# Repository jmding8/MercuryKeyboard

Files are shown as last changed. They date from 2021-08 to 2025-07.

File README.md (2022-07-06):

# Mercury

Mercury is a row staggered keyboard with 42 keys that kind of looks like a pair of wings. It is primarily designed as a split, wireless, low-profile keyboard. Other build configurations are also possible, but full feature parity is not guaranteed. If you are looking for a 40% keyboard with thumb keys and a conventional row staggered layout, then Mercury might be for you.

With MBK keycaps, Mercury is 19mm thick from table to typing-surface. Its batteries are fully enclosed and protected inside the case of the keyboard. Default firmware is pre-compiled with a keymap that I personally use exclusively and on a daily basis.

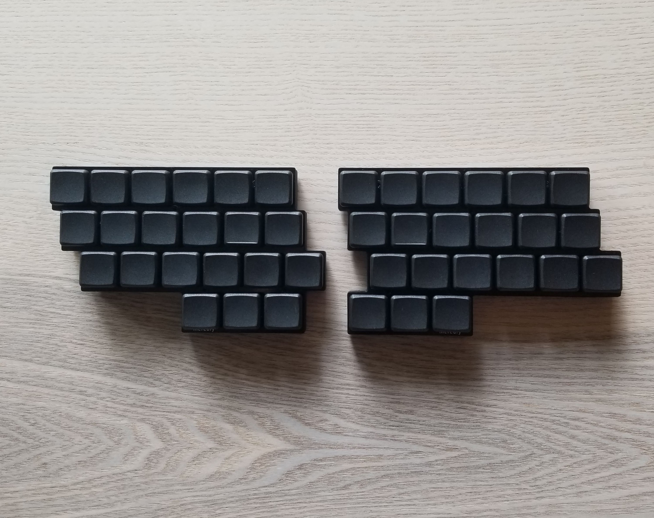
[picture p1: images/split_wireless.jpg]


## Resources
1. [Bill of materials](/text/bill_of_materials.md)
1. [Build guide](/text/build_guide.md)
1. [Manufacturing notes](/text/manufacturing_notes.md)
1. [Firmware and keymap notes](/text/firmware_notes.md)

## Alternative Configurations

* MX-style, full-height switches
* USB wired
* Monoblock, aka non-split

1. Split, wired, full-height
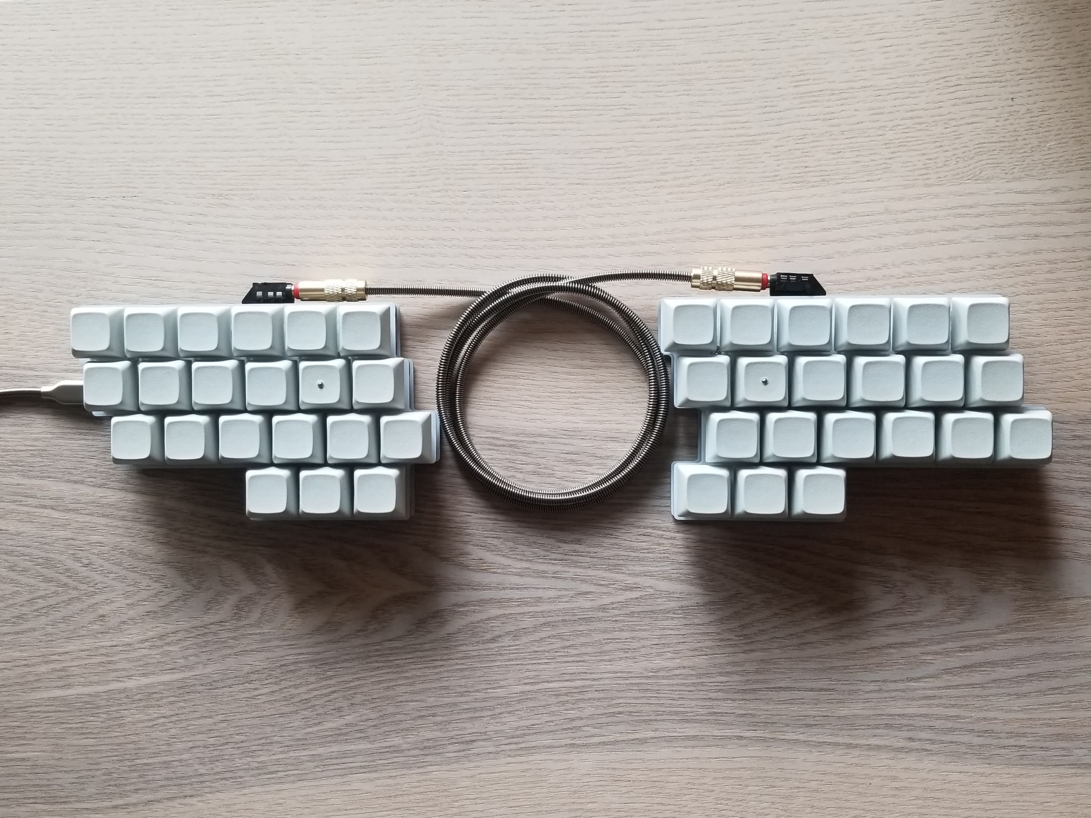
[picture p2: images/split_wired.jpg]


1. Monoblock, wireless, low-profile
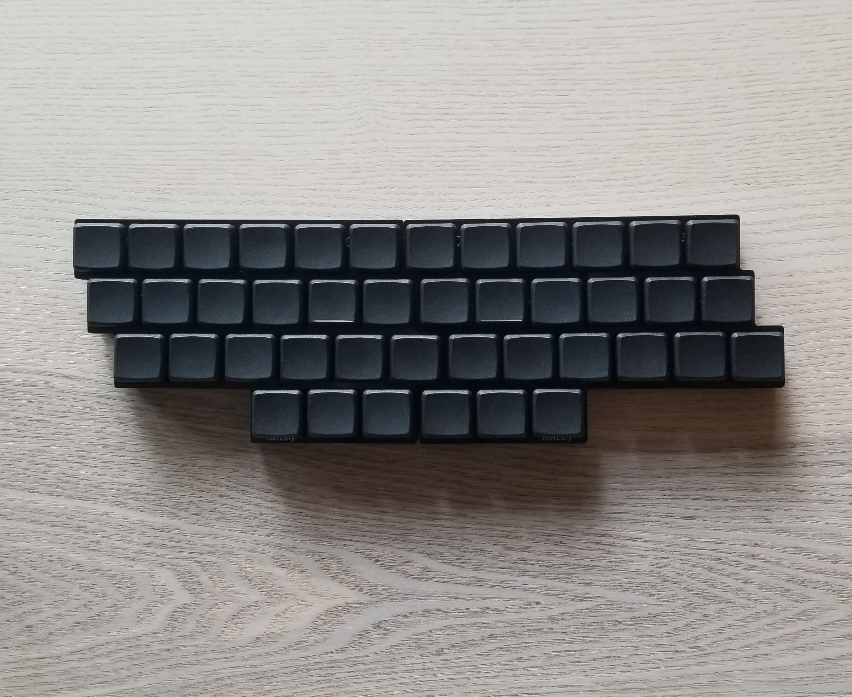
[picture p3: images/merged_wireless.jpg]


1. Monoblock, wired, low-profile
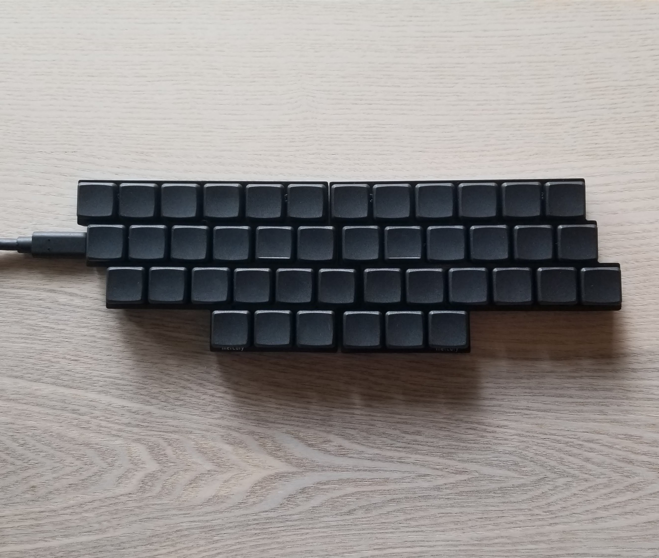
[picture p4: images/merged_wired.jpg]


## To-Do

1. Upload ZMK source.
2. Merge shield into ZMK main.

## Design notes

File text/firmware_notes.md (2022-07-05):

# Firmware and Keymap Notes

## Flashing Firmware For Wireless Builds
- See [the ZMK documentation on how to flash](https://zmk.dev/docs/user-setup#flashing-uf2-files) the firmware binaries to your keyboard.
- The default firmware binary files [are located here](/Firmware/), and are named **zmk_left.uf2** and **zmk_right.uf2**.

## Default Keymap
Mercury's default keymap seeks to achieve the following goals:
* All keyboard shortcuts should be accessible
* Reduce the use of the outer pinky columns
* Minimize the learning curve, especially:
  * Minimize the need for user-tuning of timing parameters (`tapping-term`)
  * Minimize the requirement for strict key-up order

To achieve these goals, we use several combos

### Modifier combos
1. `K` + `L` -> `Right Shift`
1. `S` + `D` -> `Left Shift`
1. `D` + `F` -> `Number Layer`
1. `S` + `D` + `F` -> `Shifted Number Layer`
1. `A` + `Function Layer` -> `Shifted Function Layer`

### Other combos
1. `X` + `C` -> `Tab`
1. `C` + `V` -> `Esc`
1. `M` + `Comma` -> `Caps Lock`
1. `H` + `J` -> `Menu Key` (opens the context menu, similar to `Right Click` in Windows)
1. `Q` + `W` + `E` -> activate `System Layer` for the next keypress

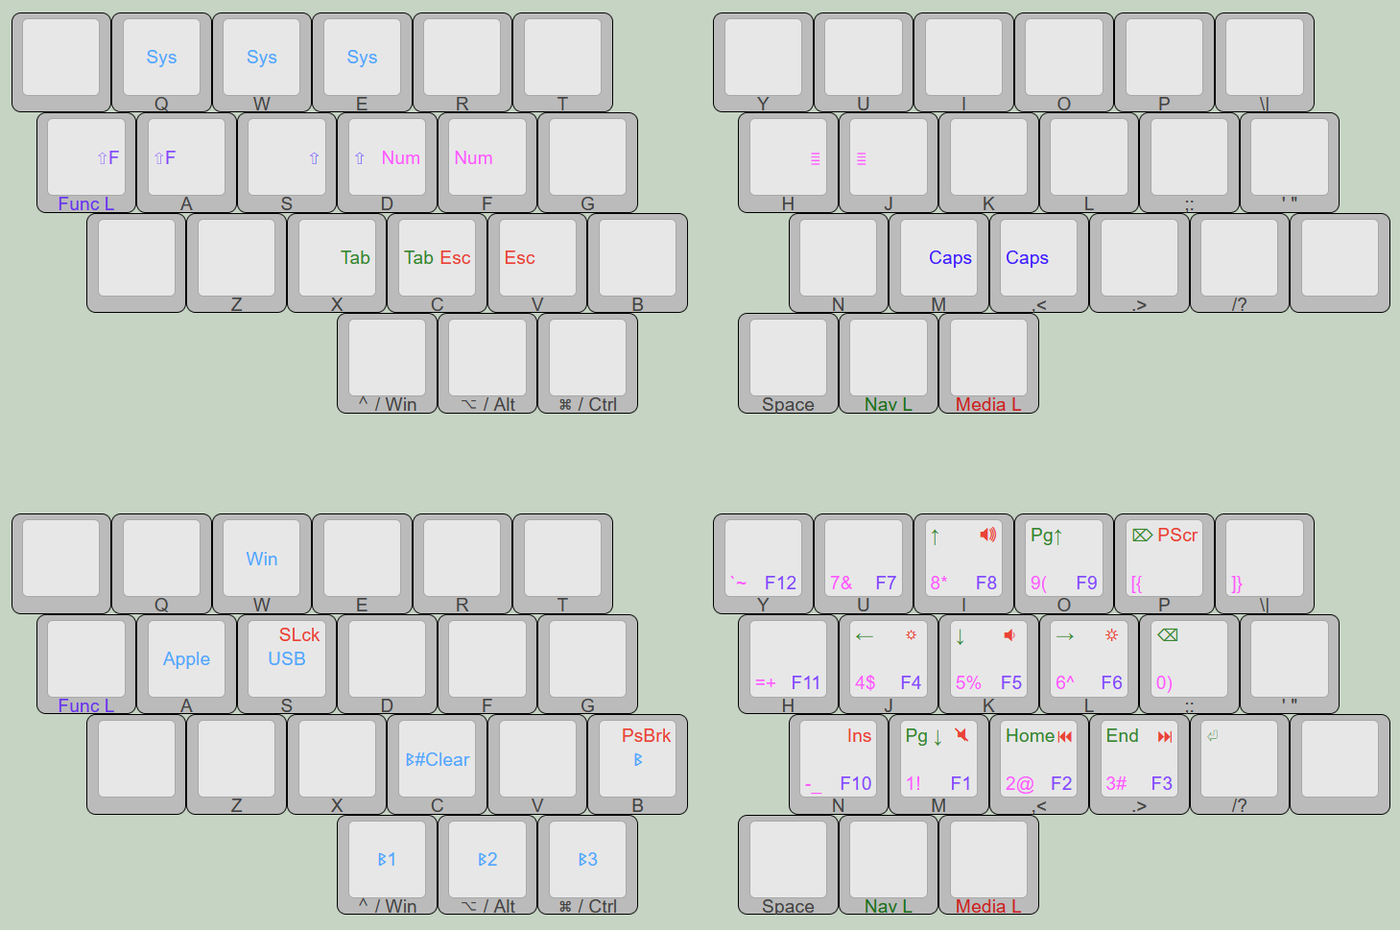
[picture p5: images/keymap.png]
keymap


## Bluetooth 
- After flashing the firmware, you will likely need to follow [the settings reset procedure described here](https://zmk.dev/docs/troubleshooting#split-keyboard-halves-unable-to-pair) to get the two keyboard halves to bond to each other, and to get the keyboard to pair with your computer.
- There are three Bluetooth profiles that can be used to pair with three computers. To select a specific profile, activate the `System Layer`, then press `Bt1` / `Bt2` / `Bt3` (left thumb cluster).
- To clear a Bluetooth profile so that it can pair with a different host, activate the profile you wish to clear. Then activate `System Layer`, and press  `BtClear` (`C` key).
- By default, the keyboard will always prefer to send output to USB when a USB cable is connected. If you want to send output over Bluetooth while chargin your keyboard over USB, you will need to enable Bluetooth-preferred output. To do this, activate `System Layer`, then press `Bluetooth` (`B` key). To enable USB-preferred output isntead, activate `System Layer`, then press `USB` (`S` key).

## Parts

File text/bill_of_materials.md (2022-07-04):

# Bill of Materials

## PCBs
- [ ] 1x left hand plate
- [ ] 1x left hand base
- [ ] 1x right-hand plate
- [ ] 1x right-hand base
- [ ] 1x logic PCB

## Additional Parts
- [ ] 42x switches, standard MX or Kailh PG1350 Chocolate
- [ ] 42x 1u keycaps
- [ ] Controller boards
  - Split + wireless: 2x Nice!Nano
  - Monoblock + wireless: 1x Nice!Nano
  - Split + wired: 2x ProMicro (Elite-C and Proton-C not verified to work)
  - Monoblock + wired: 1x ProMicro (Elite-C and Proton-C not verified to work)
- [ ] 2x reset switches, YD-3414, [available on AliExpress](https://www.aliexpress.com/item/33032223116.html)
- [ ] 24x M2 screws. 4mm long, wafer head <0.5mm thick, [available on AliExpress](https://www.aliexpress.com/item/4001149177246.html).
- [ ] 12x M2 cylindrical standoffs, <3.5mm diameter, [available on AliExpress](https://www.aliexpress.com/item/32863484622.html)
  - 7mm long for low-profile, Kailh PG1350 Chocolate switches
  - 9mm long for standard, MX style switches
- [ ] 8x Non-slip feet, >1mm thick. The below self-adhesive silicone pads, which are marketed as nose pads for glasses, are extremely non-slip and an ideal thickness. [Available on Amazon](https://www.amazon.com/Silicone-Adhesive-Non-slip-Eyeglasses-Sunglasses/dp/B072FMC99P/).
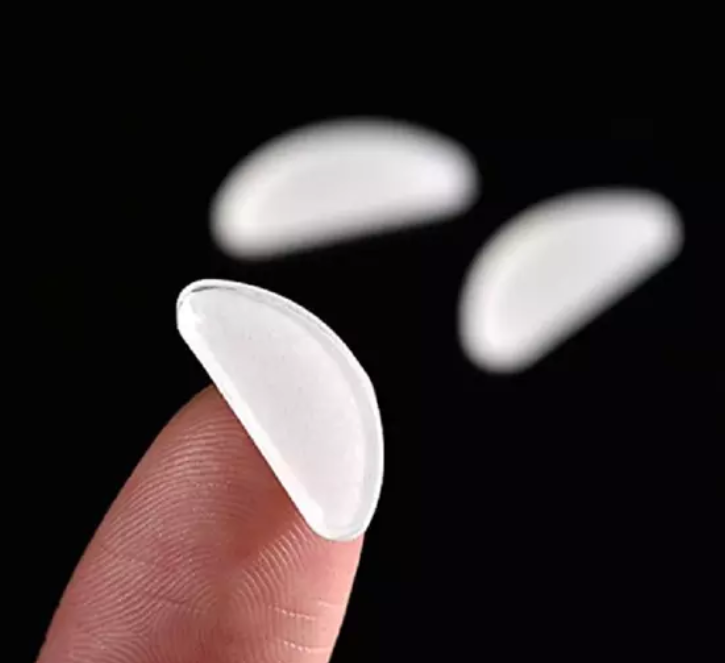
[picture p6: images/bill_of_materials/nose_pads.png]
Silicone Nose Pads

- [ ] (optional) 2x batteries. These must be smaller than 10mm wide x 44mm long x 5mm thick. 501040 batteries are the highest-capacity batteries I have found that fit. [Available on AliExpress](https://www.aliexpress.com/item/33044275929.html)
- [ ] (optional) 2x 3.5mm TRRS jacks, PJ-320A, [available on AliExpress](https://www.aliexpress.com/item/1005003561859371.html)
- [ ] (optional) 1x 3d printed left case, [see print instructions](/text/print_instructions.md)
- [ ] (optional) 1x 3d printed right case, [see print instructions](/text/print_instructions.md)
- [ ] (optional for wired+split) 1x 3.5mm TRS (mono) or TRRS (stereo) cable
- [ ] (optional) 84x Mill-Max sockets
  - 7305, 0305-0 and 0305-1 only!
  - 0305-2 sockets are too long and will NOT work!

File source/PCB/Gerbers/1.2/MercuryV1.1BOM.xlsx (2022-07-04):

Comment | Designator | Footprint | LCSC Part #（optional）
1N4148 | D1-42 | SOD-123 | C81598

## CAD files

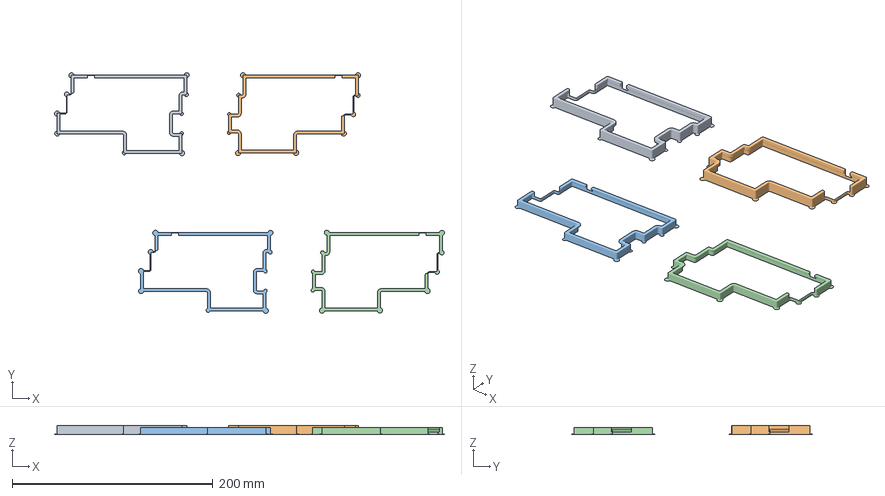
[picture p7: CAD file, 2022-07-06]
case/split_case_with_prusa_slicer_settings.3mf
388.6 x 239.8 x 8.80 mm
Merged x 4

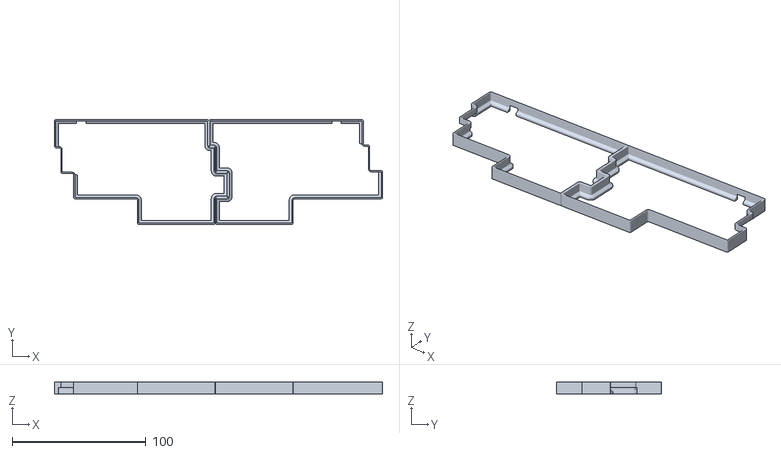
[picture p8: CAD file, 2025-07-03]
source/Case/9mm.stl
244.9 x 78.2 x 8.80

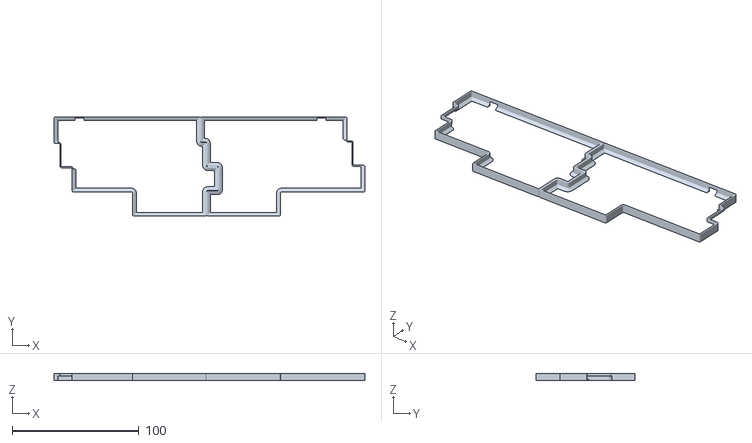
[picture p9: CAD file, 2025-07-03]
source/Case/6mm.stl
244.9 x 78.2 x 5.80

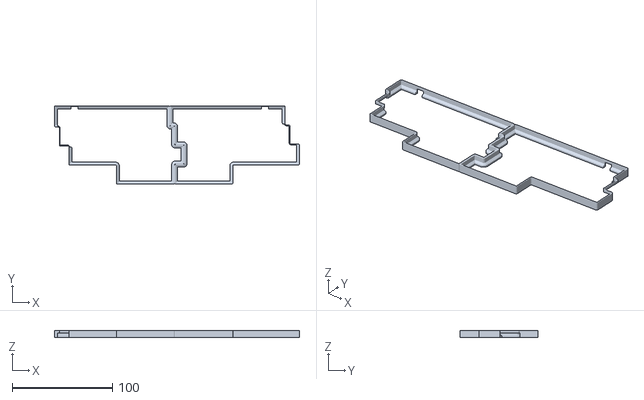
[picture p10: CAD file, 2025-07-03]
source/Case/7mm.stl
244.9 x 78.2 x 6.80

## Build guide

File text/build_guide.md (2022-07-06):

# Build Guide

## Check Bill of Materials
- [ ] Verify the contents of the [bill of materials](/text/bill_of_materials.md)

## Tools
- [ ] Flush cutters
  - Due to limited space and tight clearances, side-cutters may not be able to trim the pins close enough to the surface of the PCB. It is best to use a pair of flush-cutters instead like these, [available on Amazon](https://www.amazon.com/XURON-170-II-Micro-Shear-Flush-Cutter/dp/B07BSSG48F).
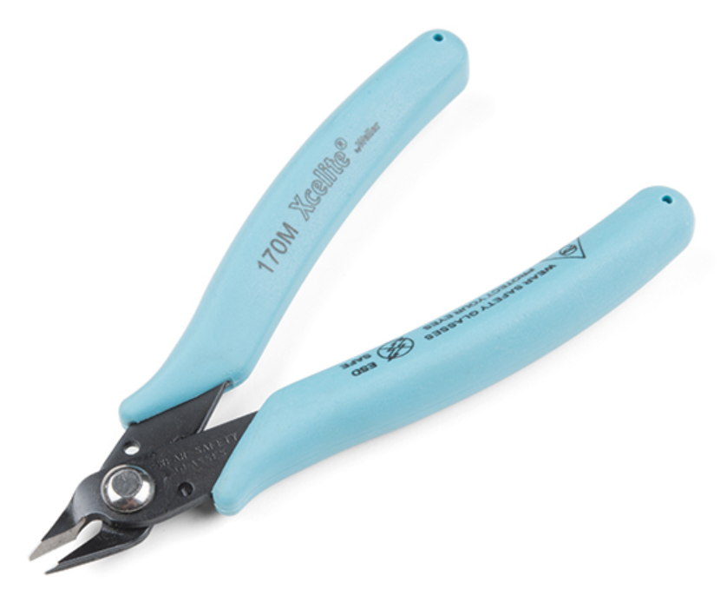
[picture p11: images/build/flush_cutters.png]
Flush Cutters
  
- [ ] Phillips screwdriver
- [ ] Soldering equipment
- [ ] Tweezers
- [ ] Tape
- [ ] (optional) Black permanent marker (Sharpie)

## Pre-build Notes
- [ ] Read all instructions before starting the build! Or at least read each sub-section before starting the steps.
- [ ] Familiarize yourself with the plates and PCB. Note the printed labels on the plates, bases, and PCB are labeled.
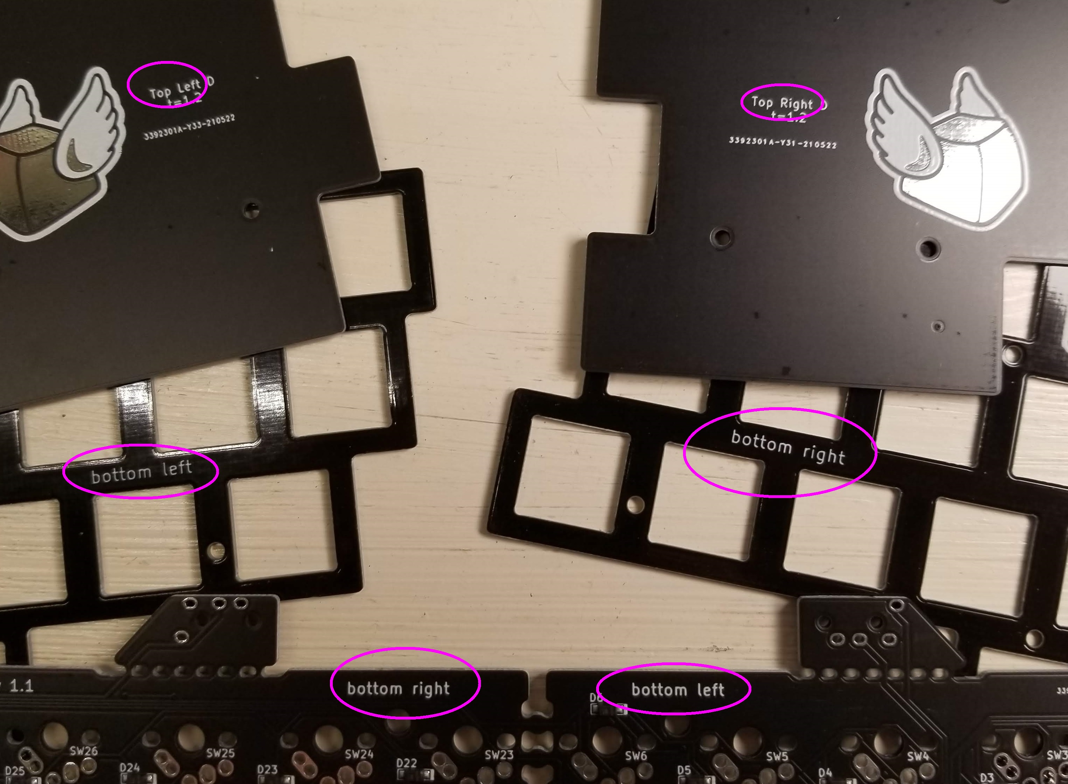
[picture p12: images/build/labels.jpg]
Labels

- [ ] This build guide uses the terms **QWERT-hand** / **HJKL-hand** and **user-side** / **table-side** to refer to the two halves of the PCB and their two respective faces. This is because the terms left/right and top/bottom get ambiguous as soon as the PCB is rotated or flipped over. Pay special attention that you are working on the correct half of the PCB and on the correct side, because it is very easy to accidentally make mistakes this way.
- [ ] Decide how you want to build your Mercury:
1. Split + wireless
mercury

1. Split + wired
mercury

1. Monoblock + wireless
mercury

1. Monoblock + wired
mercury

## TRRS sub-boards
- [ ] For **split+wired builds**, solder both TRRS jacks to the **user-side** of both halves of the PCB.
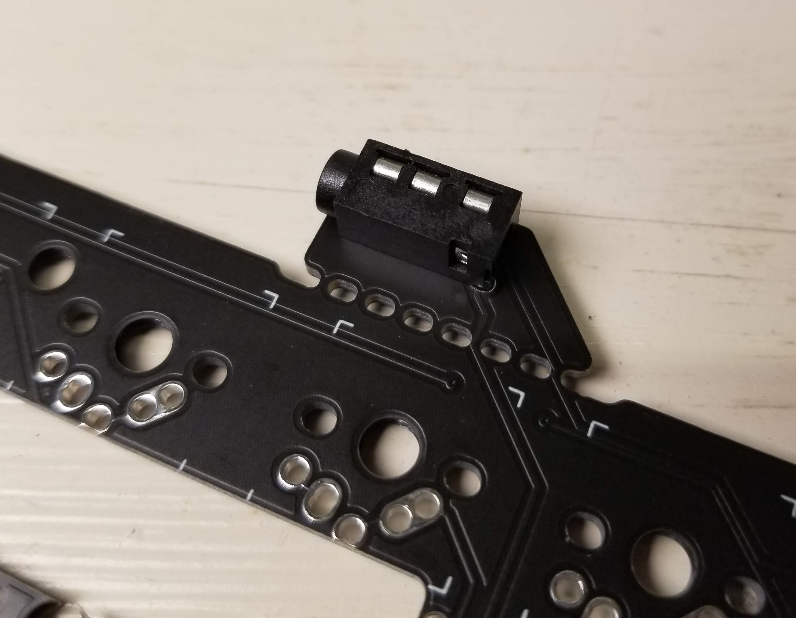
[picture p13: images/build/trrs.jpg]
Solder TTRS jacks

- [ ] For **all other builds** (split+wireless, monoblock+wireless, and monoblock+wired), snap off the TRRS sub-boards from the PCB.
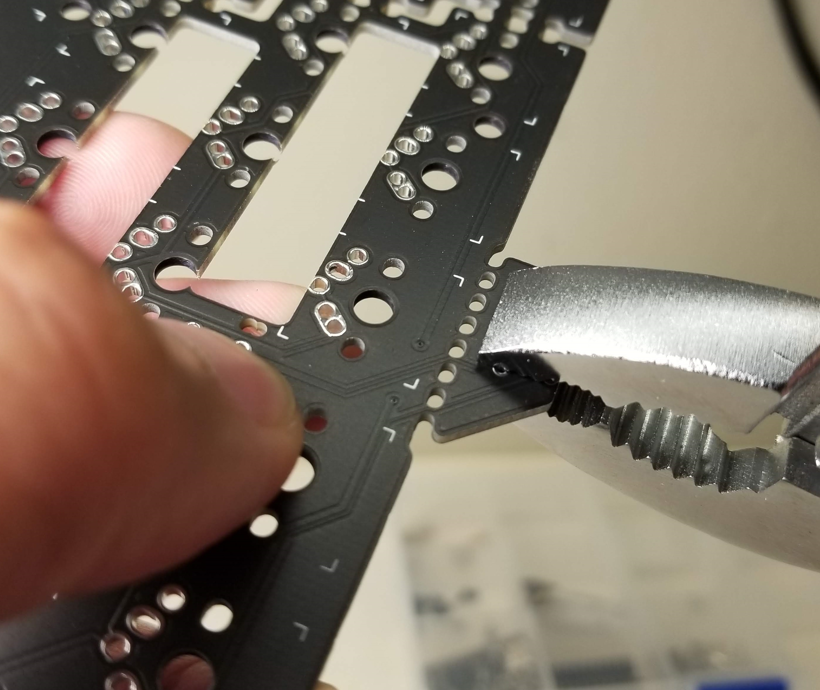
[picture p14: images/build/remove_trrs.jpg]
Snap off TRRS sub-boards


## Edge Color
- [ ] (optional) use a black permanent marker to paint the edges of the plates and bases black.

## PCB halves
  - [ ] For **monoblock builds**, skip this section.
  - [ ] For **split builds**, cut along the divots just to the left and right of the bulge in the middle of all eight PCB bridges.
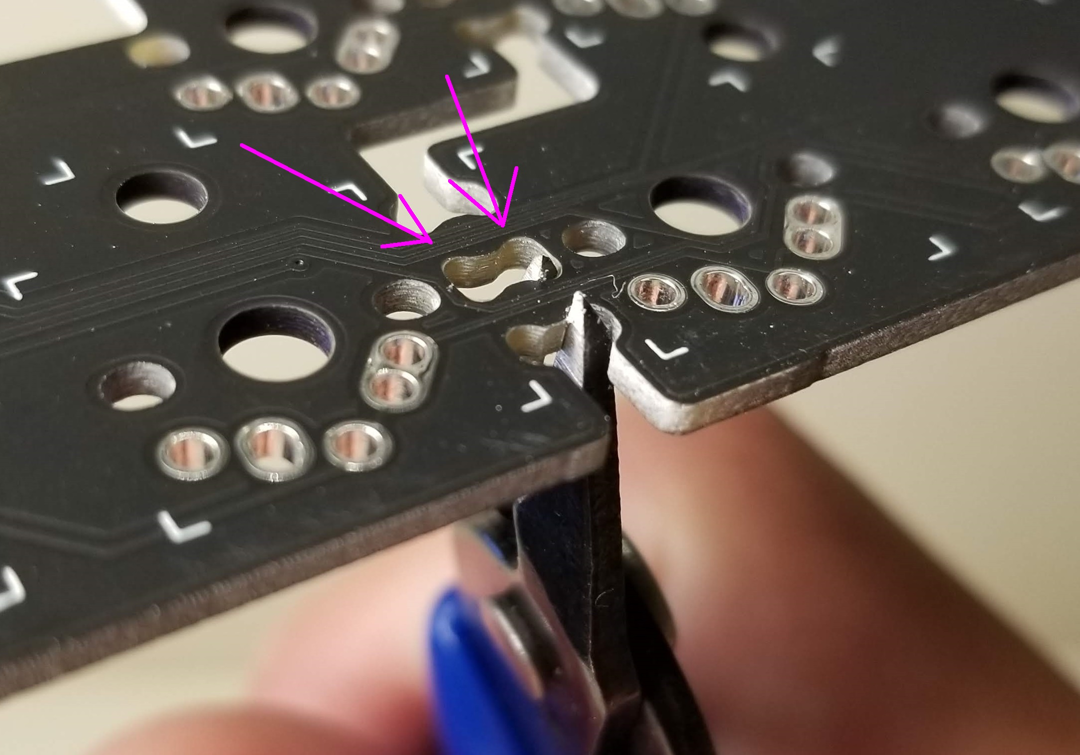
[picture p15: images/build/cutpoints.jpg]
Bridge Cut Points

  - [ ] Double check that the PCB halves sit flush against each other with no gap between them.
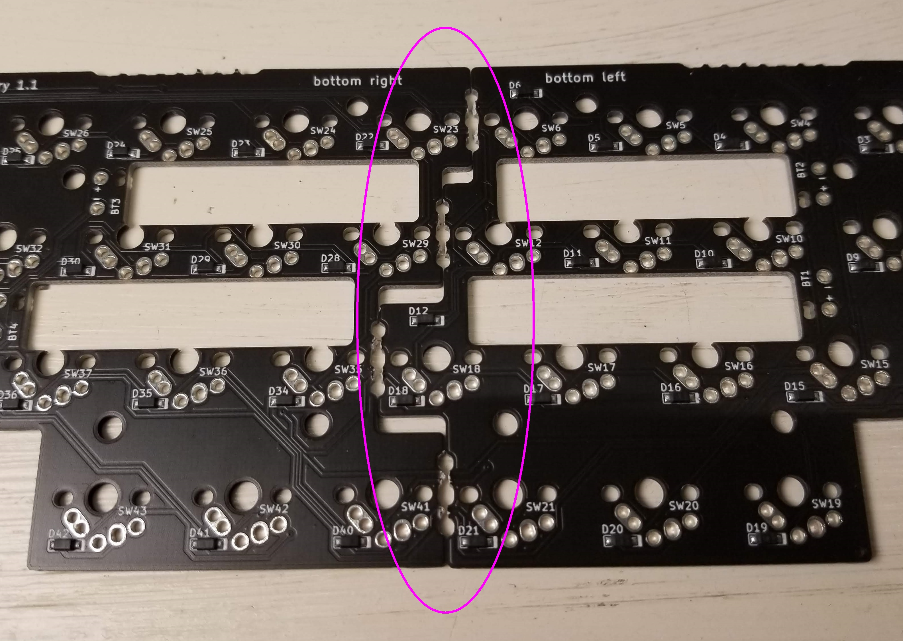
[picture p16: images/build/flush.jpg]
Flush PCBs


## Controller board header pins
- [ ] Shorten two strips of header pins to 10 pins long.
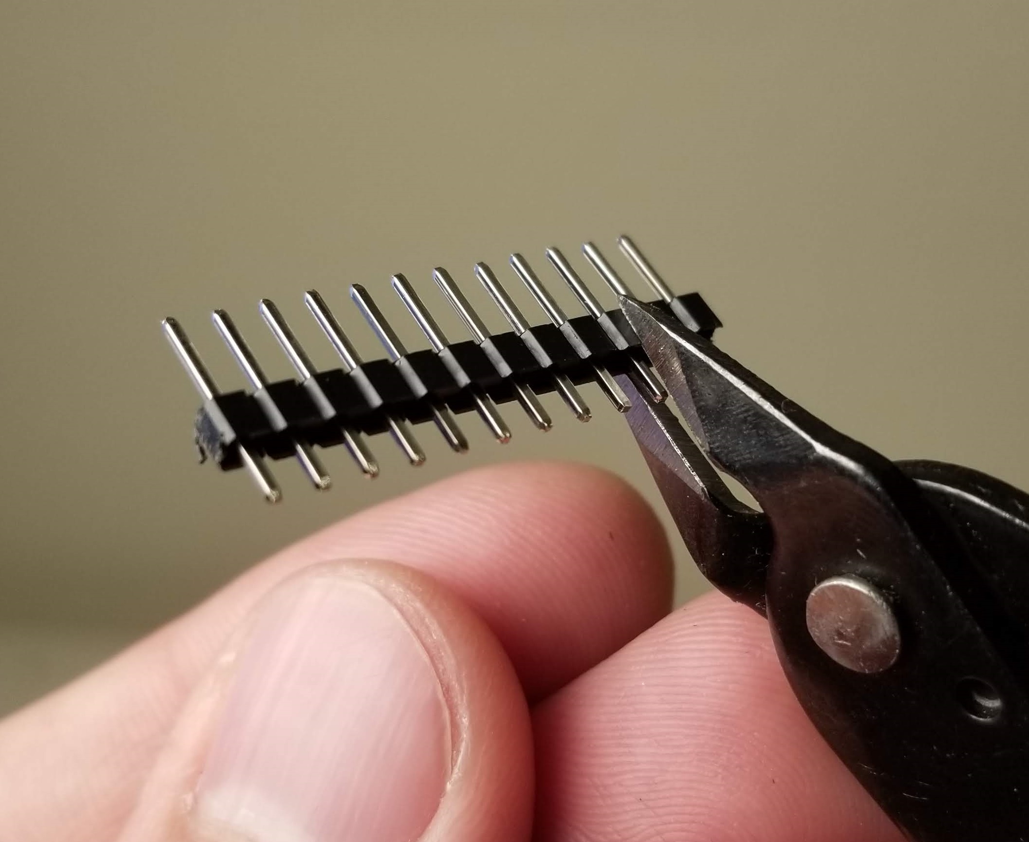
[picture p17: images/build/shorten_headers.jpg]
Shorten header pin strips

- [ ] Insert the **short legs** of the header pin strips into the **QWERT-hand** half of the PCB, through the **table-side**.
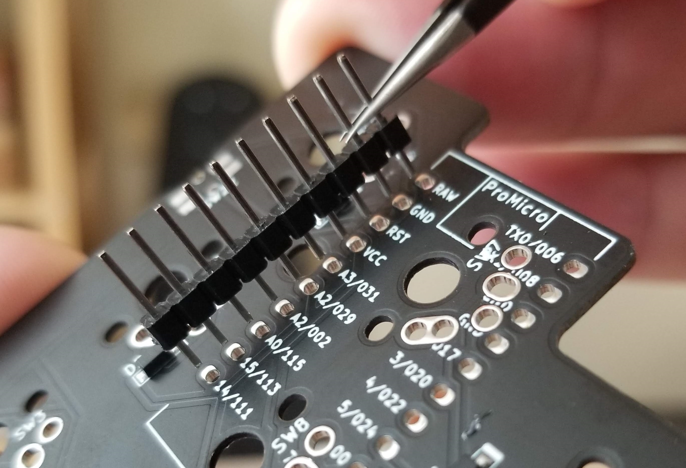
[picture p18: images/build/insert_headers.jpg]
Insert header pin strips

- [ ] Double check that the **short legs** of the header pins are inserted into the PCB.
- [ ] Double check that the header pins inserted down through the **table-side** of the PCB.
- [ ] Double check that the header pins are inserted into the **QWERT-hand** half of the PCB.
- [ ] Place the controller onto the header pins and use a piece of tape to hold everything together temporarily.
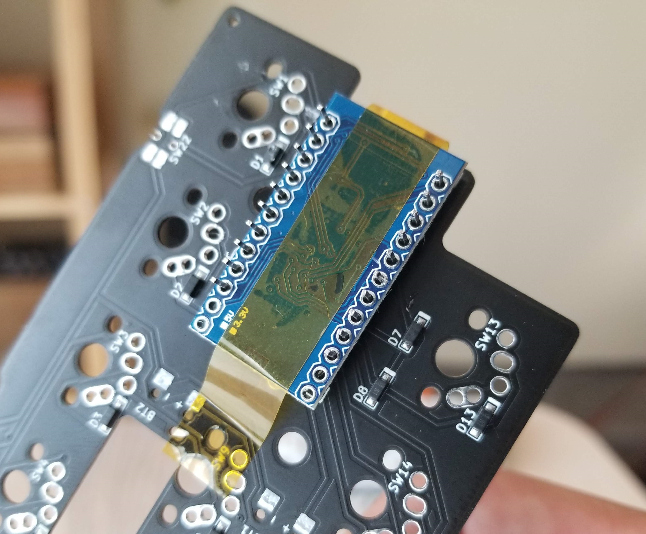
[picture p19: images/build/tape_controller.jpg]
Tape controller in place

- [ ] Using flush cutters, trim the header pins flat to the surface of the PCB.
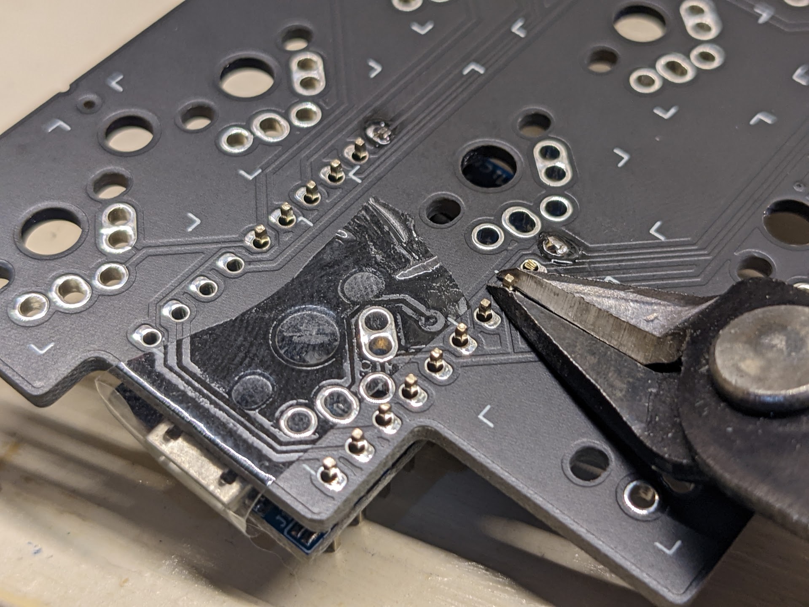
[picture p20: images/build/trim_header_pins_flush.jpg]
Trim header pins flush

- [ ] Solder the header pins **to the PCB only**. Do not solder the controller board.
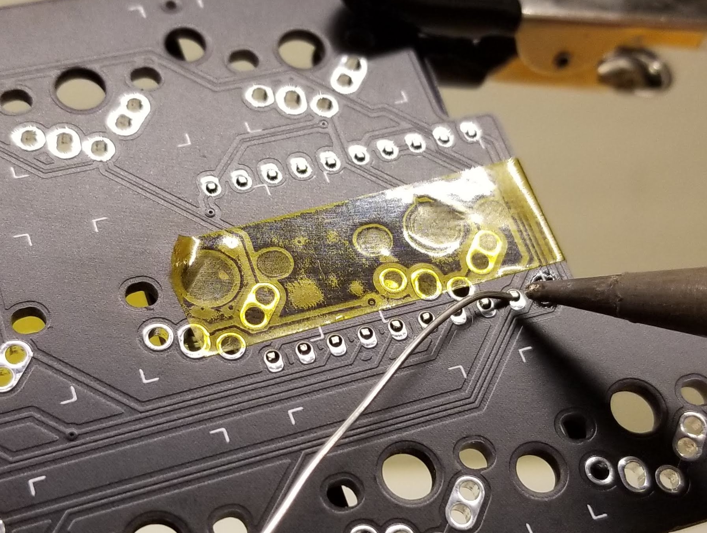
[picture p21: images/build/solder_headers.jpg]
Solder header pin strips to PCB

- [ ] Remove the controller board and set it aside for now.
- [ ] For **split builds**, repeat this process for the second set of header pins on the **HJKL-hand** half of the PCB.

## Optional: remove spacers from headers
- [ ] This step is optional but recommended. It makes it easier to remove the controller boards later if they need to be replaced for repair, upgrade, or other purposes.
- [ ] Use pliers to carefully pull the plastic spacers off of the headers. They should slide off with gentle rocking and pulling.
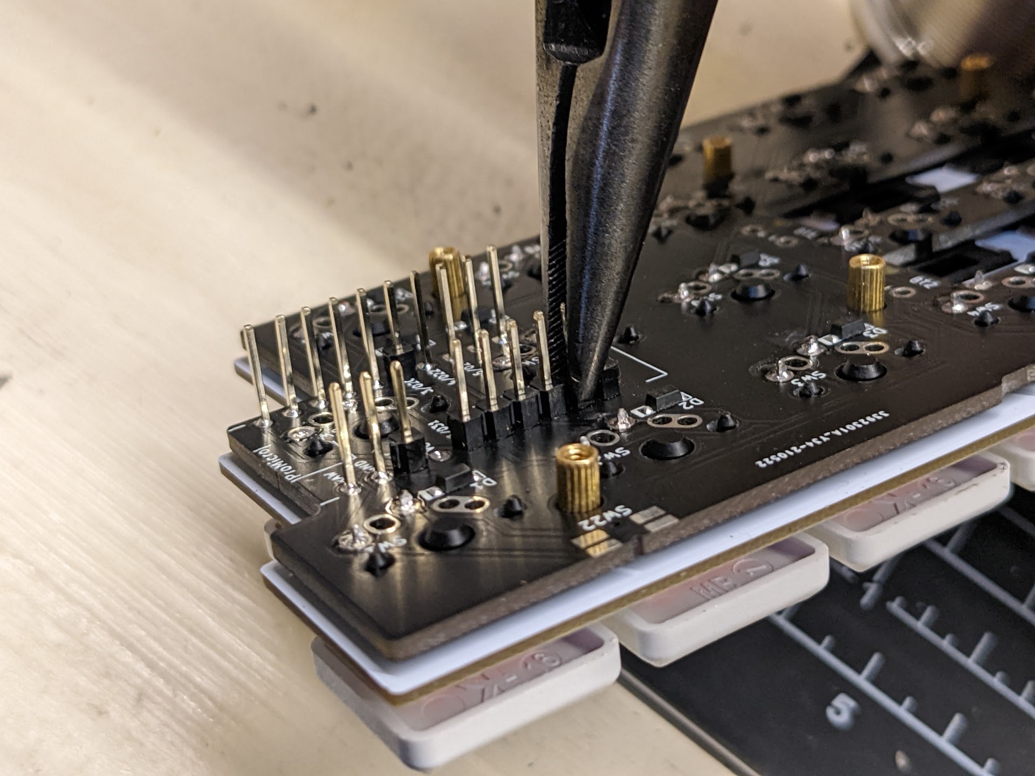
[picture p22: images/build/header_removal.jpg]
Remove plastic spacers

- [ ] It is still necessary to precisely space the controller board away from the PCB. To facilitate this, cut 6x single-pin spacers from the strip. Reinstall three of these single-pin spacers roughly where pictured, and repeat for the second controller.
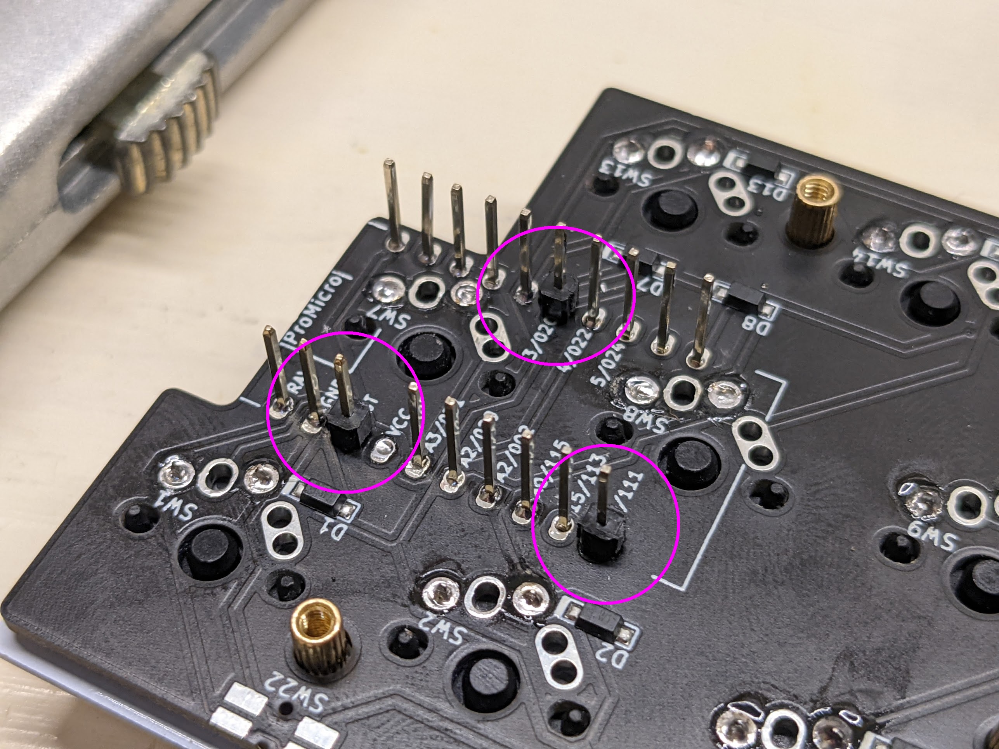
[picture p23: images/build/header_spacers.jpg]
Reinstall trimmed spacers


## Reset switches
- [ ] Solder the reset switch to the **table-side** of the **QWERT-hand** half of the PCB.
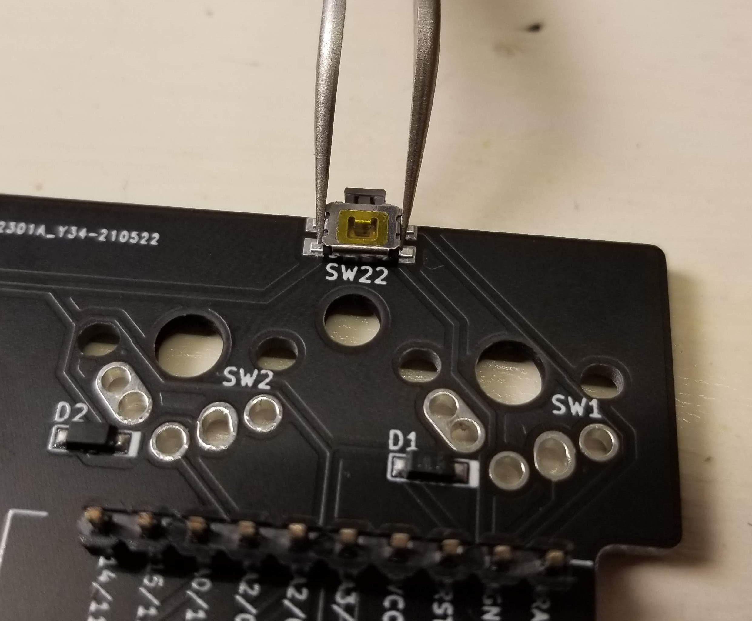
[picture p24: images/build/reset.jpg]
Reset switch

- [ ] For **split builds**, also solder a reset switch to the **table-side** of the **HJKL-hand** half of the PCB.

## Switches
- [ ] Screw the standoffs securely to the **table-side** of both plates.
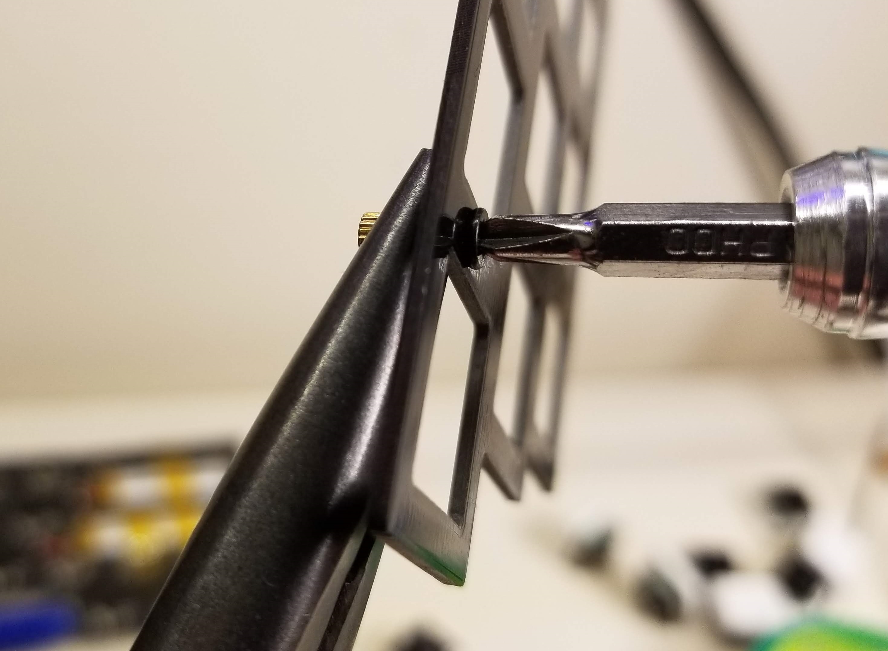
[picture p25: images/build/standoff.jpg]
Attach standoffs

- [ ] Using flush cutters, trim the legs of four switches flush with the PCB. This is to prevent these switches from accidentally short circuiting against the controller boards.
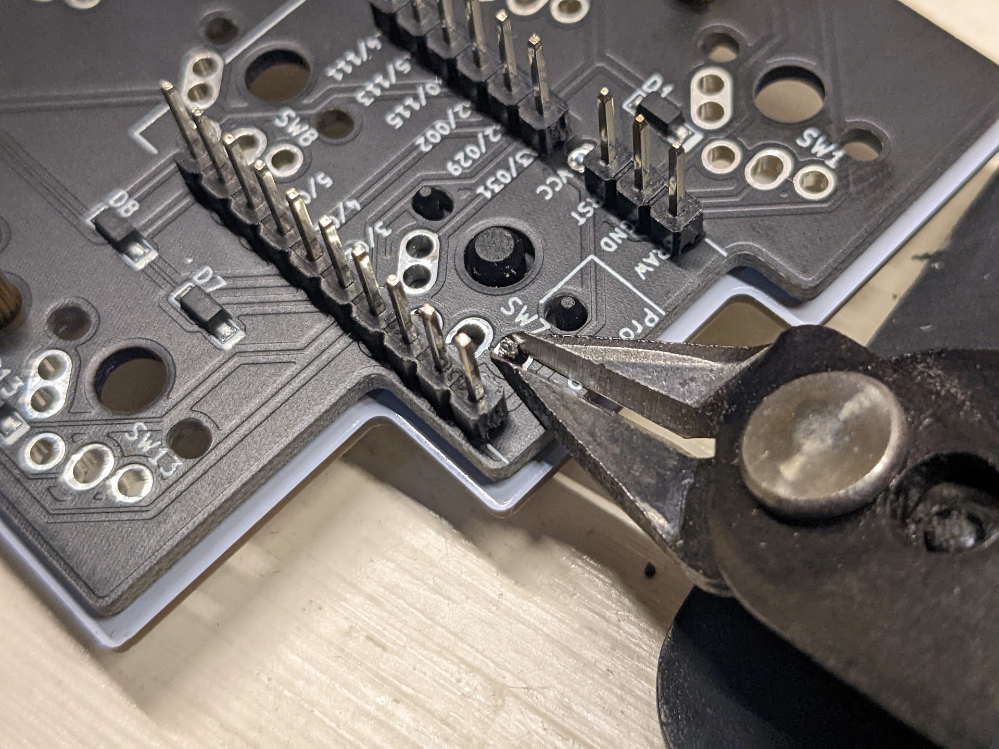
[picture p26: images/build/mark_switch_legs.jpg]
Trim switch legs

- [ ] Snap all of the switches into the plate.
- [ ] Double check that the four switches with the trimmed legs are positioned directly over the controller boards.
- [ ] It is best to install all of the switches into the plate before soldering. Once you start soldering, it becomes very difficult to make sure that all of the switches are fully pressed into the plate.
- [ ] If you are using Mill-max hot-swap sockets, solder them into the PCB now.
- [ ] Place the plate + switch assembly onto the PCB.
- [ ] Double check that all of the switch legs fit into their respective holes in the PCB, and have not been bent out of place.
- [ ] Solder all of the switches in place.

## Batteries
- [ ] For **wired builds**, skip this section
- [ ] For **wireless builds**, place a battery into the battery cutout labeled **BT1** in the **QWERT-hand** half of the PCB and tape it in place.
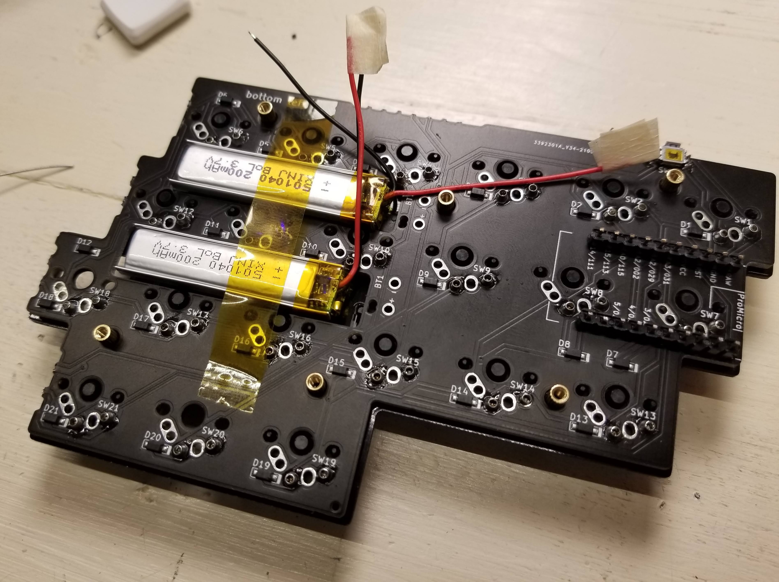
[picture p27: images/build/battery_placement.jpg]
Battery placement

- [ ] Solder the black wire to the PCB pad marked -. Then solder the red wire to the PCB pad marked +
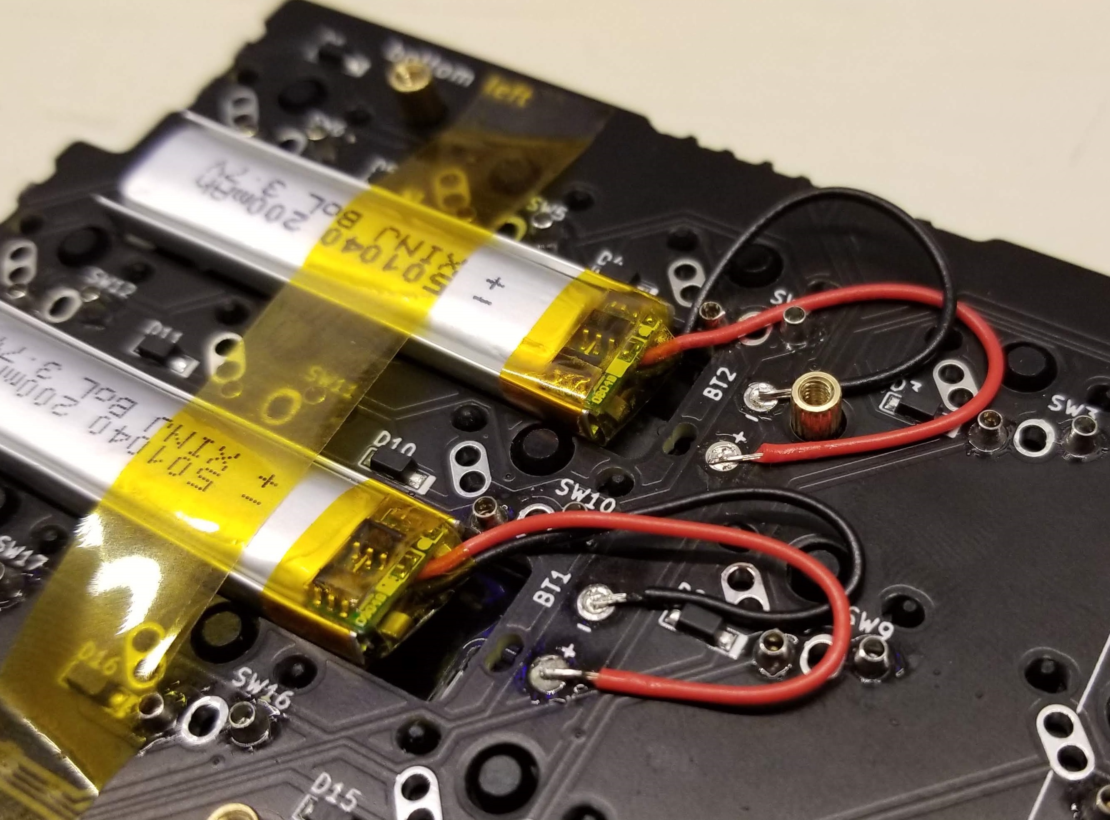
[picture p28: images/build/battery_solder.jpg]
Solder batteries

- [ ] For **split builds**, repeat the process of securing and soldering a battery into the cutout labeled **BT3** in the **HJKL-hand** half of the PCB.
- [ ] (Optional) if you want extra battery life, you can add additional batteries to battery bays **BT2** and **BT4**.

## Controller boards
- [ ] Place a controller board onto the header pins of the **QWERT-hand** half of the PCB, with the controller board components facing the PCB.
- [ ] Double check that the controller boards have all of their components facing the PCB, with the smooth side of the controller board facing the table.
- [ ] Double check that there are two through holes on the controller boards opposite the USB port that do NOT have header pins in them.
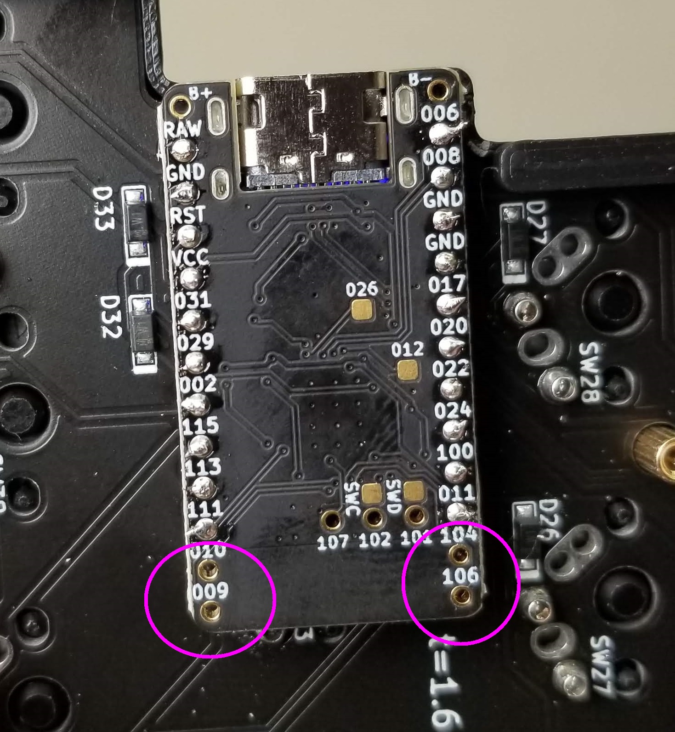
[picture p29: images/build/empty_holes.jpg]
Empty through-holes

- [ ] Solder the controller boards in place.
- [ ] Trim the header pins flush with the controller boards.

## Final assembly
- [ ] (Optional) install the plastic case around the PCB, being careful to slip it around the reset switch and controller board.
- [ ] Screw the bases in place. Do not over tighten the screws, or the keyboard may bend and not sit flat.
- [ ] Apply anti-slip feet.
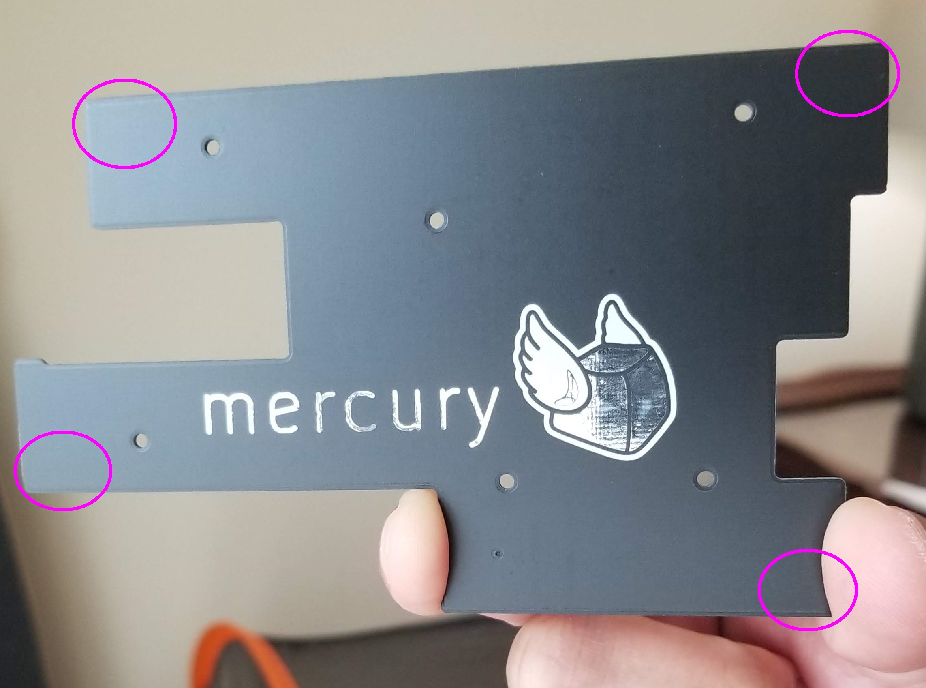
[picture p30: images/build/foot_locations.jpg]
Foot location


## Firmware

See the [Firmware Notes](/text/firmware_notes.md)

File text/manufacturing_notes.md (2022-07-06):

# Manufacturing Notes

## PCBs
* [The PCB files are here](/pcb/v1.2).
* There are 5 total PCB files. They were designed with specific thicknesses for clearance reasons:
  * Logic PCB: 1.6mm
  * Left base: 1.2mm
  * Right base: 1.2mm
  * Left plate: 1.2mm
  * Right plate: 1.2mm
* It is strongly recommended to have the diodes pre-soldered by the PCB manufacturer.

## Optional 3D Printed Case

### Split builds
* [The case files are here](/case/split_case_with_prusa_slicer_settings.3mf). Included in the file are the low-profile cases, as well as the full-height cases.
* For wired builds, delete Body53_1 and Body54_1 to make room for the TRRS sub-boards to stick out through.
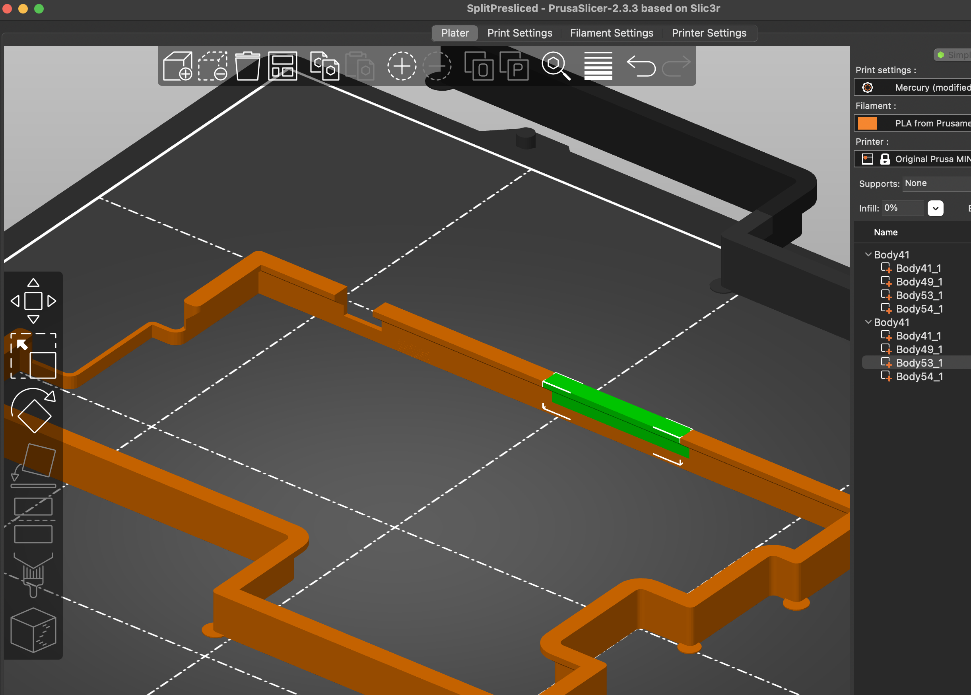
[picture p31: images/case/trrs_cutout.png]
TRRS cutouts in green

* The case is designed around PrusaSlicer. Cura (as of 2021) handles thin walls poorly, and also treats adjoining parts differently.
* Use PrusaSlicer and open the 3mf file as a project file (and not as a pure geometry / mesh).
* The project file includes slicer settings which implement many tweaks and optimizations that help maximize print quality.
* The top part was printed from the project file. The bottom part was sliced more conventionally.
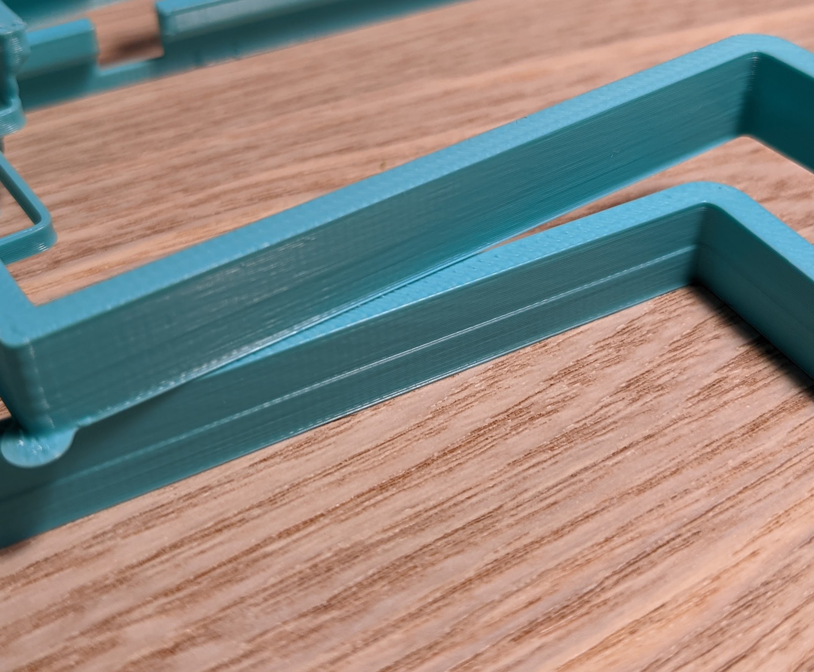
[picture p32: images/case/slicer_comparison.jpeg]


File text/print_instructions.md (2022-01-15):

# 3d Printed Case

## Instructions

* For wired, split builds, delete Body53_1 and Body54_1 to make room for the TRRS sub-boards to stick out through.
TRRS cutouts in green
* The case is designed assuming PrusaSlicer. Cura handles thin walls poorly, and also treats adjoining parts differently.
* Use PrusaSlicer to open the .3mf file as a project file (and not as a pure geometry / mesh).
* The project file includes slicer settings which implement many tweaks and optimizations that help maximize print quality.
* The top part was printed from the project file. The bottom part was sliced more conventionally.
TRRS cutouts in green

## Files
1. [Case file(s) for all split builds](/case/split_case_with_prusa_slicer_settings.3mf)
1. ~~Case file for merged builds~~ Not yet available

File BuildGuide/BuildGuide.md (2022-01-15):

# Build Guide

## Check Kit Contents
- [ ] 1x QWERT-hand plate
- [ ] 1x HJKL-hand plate
- [ ] 1x QWERT-hand base
- [ ] 1x HJKL-hand base
- [ ] 1x PCB
- [ ] 2x reset switches (YD-3414)
- [ ] 24x M2 screws (4mm, wafer head)
- [ ] 12x cylindrical standoffs (<3.5mm diameter)
  - 7mm for low-profile, Kailh PG1350 Chocolate switches
  - 9mm for standard, MX style switches
- [ ] 8x Non-slip feet
- [ ] (optional) 2x batteries
- [ ] (optional) 2x 3.5mm TRRS jacks, PJ-320A
- [ ] (optional) 1x left case
- [ ] (optional) 1x right case

## Gather Additional Parts
- [ ] 42x switches, standard MX or Kailh PG1350 Chocolate
- [ ] 42x 1u keycaps
- [ ] Controller boards
  - Split + wireless: 2x Nice!Nano
  - Single_piece + wireless: 1x Nice!Nano
  - Split + wired: 2x ProMicro (Elite-C and Proton-C not yet verified to work)
  - Single_pice + wired: 1x ProMicro (Elite-C and Proton-C not yet verified to work)
- [ ] (optional for wired+split) 1x 3.5mm TRS (mono) or TRRS (stereo) cable
- [ ] (optional) 84x Mill-Max sockets
  - 7305, 0305-0 and 0305-1 only!
  - 0305-2 sockets are too long and will NOT work!

## Gather Tools
- [ ] Flush cutter
  - Due to limited space and tight clearances, typical side-cutters may not be able to trim the pins close enough to the surface of the PCB. It is best to use a pair of flush-cutters instead, [such as these](https://www.amazon.com/XURON-170-II-Micro-Shear-Flush-Cutter/dp/B07BSSG48F).
- [ ] Phillips screwdriver
- [ ] Soldering equipment
- [ ] Tweezers
- [ ] Tape
- [ ] (optional) Black permanent marker (Sharpie)

## Pre-build Notes
- [ ] Read all instructions before starting the build! Or at least read each sub-section before starting the steps.
- [ ] Familiarize yourself with the plates and PCB. Note the printed labels on the plates, bases, and PCB are labeled.
Labels
- [ ] This build guide uses the terms **QWERT-hand** / **HJKL-hand** and **user-side** / **table-side** to refer to the two halves of the PCB and their two respective faces. This is because the terms left/right and top/bottom get ambiguous as soon as the PCB is rotated or flipped over. Pay special attention that you are working on the correct half of the PCB and on the correct side, because it is very easy to accidentally make mistakes this way.
- [ ] Decide how you want to build your Mercury:
1. Split + wireless
mercury

1. Split + wired
mercury

1. Single-piece + wireless
mercury

1. Single-piece + wired
mercury

## TRRS sub-boards
- [ ] For **split+wired builds**, solder both TRRS jacks to the **user-side** of both halves of the PCB.
Solder TTRS jacks
- [ ] For **all other builds** (split+wireless, single_piece+wireless, and single_piece+wired), snap off the TRRS sub-boards from the PCB.
Snap off TRRS sub-boards

## Edge Color
- [ ] (optional) use a black permanent marker to paint the edges of the plates and bases black.

## PCB halves
  - [ ] For **single_piece builds**, skip this section.
  - [ ] For **split builds**, cut along the divots just to the left and right of the bulge in the middle of all eight PCB bridges.
Bridge Cut Points
  - [ ] Double check that the PCB halves sit flush against each other with no gap between them.
Flush PCBs

## Controller board header pins
- [ ] Shorten two strips of header pins to 10 pins long.
Shorten header pin strips
- [ ] Insert the **short legs** of the header pin strips into the **QWERT-hand** half of the PCB, through the **table-side**.
Insert header pin strips
- [ ] Double check that the **short legs** of the header pins are inserted into the PCB.
- [ ] Double check that the header pins inserted down through the **table-side** of the PCB.
- [ ] Double check that the header pins are inserted into the **QWERT-hand** half of the PCB.
- [ ] Place the controller onto the header pins and use a piece of tape to hold everything together temporarily.
Tape controller in place
- [ ] Using flush cutters, trim the header pins flat to the surface of the PCB.
Trim header pins flush
- [ ] Solder the header pins **to the PCB only**. Do not solder the controller board.
Solder header pin strips to PCB
- [ ] Remove the controller board and set it aside for now.
- [ ] For **split builds**, repeat this process for the second set of header pins on the **HJKL-hand** half of the PCB.

## Optional: remove spacers from headers
- [ ] This step is optional but recommended. It makes it easier to remove the controller boards later if they need to be replaced for repair, upgrade, or other purposes.
- [ ] Use pliers to carefully pull the plastic spacers off of the headers. They should slide off with gentle rocking and pulling.
Remove plastic spacers
- [ ] It is still necessary to precisely space the controller board away from the PCB. To facilitate this, cut 6x single-pin spacers from the strip. Reinstall three of these single-pin spacers roughly where pictured, and repeat for the second controller.
Reinstall trimmed spacers

## Reset switches
- [ ] Solder the reset switch to the **table-side** of the **QWERT-hand** half of the PCB.
Reset switch
- [ ] For **split builds**, also solder a reset switch to the **table-side** of the **HJKL-hand** half of the PCB.

## Switches
- [ ] Screw the standoffs securely to the **table-side** of both plates.
Attach standoffs
- [ ] Using flush cutters, trim the legs of four switches flush with the PCB. This is to prevent these switches from accidentally short circuiting against the controller boards.
Trim switch legs
- [ ] Snap all of the switches into the plate.
- [ ] Double check that the four switches with the trimmed legs are positioned directly over the controller boards.
- [ ] It is best to install all of the switches into the plate before soldering. Once you start soldering, it becomes very difficult to make sure that all of the switches are fully pressed into the plate.
- [ ] If you are using Mill-max hot-swap sockets, solder them into the PCB now.
- [ ] Place the plate + switch assembly onto the PCB.
- [ ] Double check that all of the switch legs fit into their respective holes in the PCB, and have not been bent out of place.
- [ ] Solder all of the switches in place.

## Batteries
- [ ] For **wired builds**, skip this section
- [ ] For **wireless builds**, place a battery into the battery cutout labeled **BT1** in the **QWERT-hand** half of the PCB and tape it in place.
Battery placement
- [ ] Solder the black wire to the PCB pad marked -. Then solder the red wire to the PCB pad marked +
Solder batteries
- [ ] For **split builds**, repeat the process of securing and soldering a battery into the cutout labeled **BT3** in the **HJKL-hand** half of the PCB.
- [ ] (Optional) if you want extra battery life, you can add additional batteries to battery bays **BT2** and **BT4**.

## Controller boards
- [ ] Place a controller board onto the header pins of the **QWERT-hand** half of the PCB, with the controller board components facing the PCB.
- [ ] Double check that the controller boards have all of their components facing the PCB, with the smooth side of the controller board facing the table.
- [ ] Double check that there are two through holes on the controller boards opposite the USB port that do NOT have header pins in them.
Empty through-holes
- [ ] Solder the controller boards in place.
- [ ] Trim the header pins flush with the controller boards.

## Final assembly
- [ ] (Optional) install the plastic case around the PCB, being careful to slip it around the reset switch and controller board.
- [ ] Screw the bases in place. Do not over tighten the screws, or the keyboard may bend and not sit flat.
- [ ] Apply anti-slip feet.
Foot location

## Firmware

See the [Firmware Guide](/BuildGuide/FirmwareGuide.md)

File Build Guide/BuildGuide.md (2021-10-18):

# Build Guide

*** 

## Check Kit Contents
- [ ] 1x QWERT-hand plate
- [ ] 1x HJKL-hand plate
- [ ] 1x QWERT-hand base
- [ ] 1x HJKL-hand base
- [ ] 1x PCB
- [ ] 2x reset switches (YD-3414)
- [ ] 24x M2 screws (4mm, wafer head)
- [ ] 12x standoffs (~3mm diameter, brass)
  - 7mm for low-profile, Kailh PG1350 Chocolate switches
  - 9mm for standard, MX style switches
- [ ] 8x Non-slip feet
- [ ] (optional) 2x batteries
- [ ] (optional) 2x 3.5mm TRRS jacks, PJ-320A
- [ ] (optional) 1x left case
- [ ] (optional) 1x right case

*** 

## Gather Additional Parts
- [ ] 42x switches, standard MX or Kailh PG1350 Chocolate
- [ ] 42x 1u keycaps
- [ ] Controller boards
  - Split + wireless: 2x Nice!Nano
  - Single_piece + wireless: 1x Nice!Nano
  - Split + wired: 2x ProMicro (Elite-C and Proton-C not yet verified to work)
  - Single_pice + wired: 1x ProMicro (Elite-C and Proton-C not yet verified to work)
- [ ] (optional for wired+split) 1x 3.5mm TRS (mono) or TRRS (stereo) cable
- [ ] (optional) 84x Mill-Max sockets
  - 7305, 0305-0 and 0305-1 only!
  - 0305-2 sockets are too long and will NOT work!

*** 

## Gather Tools
- [ ] Flush cutter
  - Due to limited space and tight clearances, typical side-cutters may not be able to trim the pins close enough to the surface of the PCB. It is best to use a pair of flush-cutters instead, [such as these](https://www.amazon.com/XURON-170-II-Micro-Shear-Flush-Cutter/dp/B07BSSG48F).
- [ ] Phillips screwdriver
- [ ] Soldering equipment
- [ ] Tweezers
- [ ] Tape
- [ ] (optional) Black permanent marker (Sharpie)

*** 

## Pre-build Notes
- [ ] Read all instructions before starting the build! Or at least read each sub-section before starting the steps.
- [ ] Familiarize yourself with the plates and PCB. Note the printed labels on the plates, bases, and PCB are labeled.
Labels
- [ ] This build guide uses the terms **QWERT-hand** / **HJKL-hand** and **user-side** / **table-side** to refer to the two halves of the PCB and their two respective faces. This is because the terms left/right and top/bottom get ambiguous as soon as the PCB is rotated or flipped over. Pay special attention that you are working on the correct half of the PCB and on the correct side, because it is very easy to accidentally make mistakes this way.
- [ ] Decide how you want to build your Mercury:
1. Split + wireless
mercury

1. Split + wired
mercury

1. Single-piece + wireless
mercury

1. Single-piece + wired
mercury

***

## TRRS sub-boards
- [ ] For **split+wired builds**, solder both TRRS jacks to the **user-side** of both halves of the PCB.
Solder TTRS jacks
- [ ] For **all other builds** (split+wireless, single_piece+wireless, and single_piece+wired), snap off the TRRS sub-boards from the PCB.
Snap off TRRS sub-boards

*** 

## Edge Color
- [ ] (optional) use a black permanent marker to paint the edges of the plates and bases black.

*** 

## PCB halves
  - [ ] For **single_piece builds**, skip this section.
  - [ ] For **split builds**, cut along the divots just to the left and right of the bulge in the middle of all eight PCB bridges.
Bridge Cut Points
  - [ ] Double check that the PCB halves sit flush against each other with no gap between them.
Flush PCBs

*** 

## Controller board header pins
- [ ] Shorten two strips of header pins to 10 pins long.
Shorten header pin strips
- [ ] Insert the **short legs** of the header pin strips into the **QWERT-hand** half of the PCB, through the **table-side**.
Insert header pin strips
- [ ] Double check that the **short legs** of the header pins are inserted into the PCB.
- [ ] Double check that the header pins inserted down through the **table-side** of the PCB.
- [ ] Double check that the header pins are inserted into the **QWERT-hand** half of the PCB.
- [ ] Place the controller onto the header pins and use a piece of tape to hold everything together temporarily.
Tape controller in place
- [ ] Solder the header pins **to the PCB only**. Do not solder the controller board.
Solder header pin strips to PCB
- [ ] Remove the controller board and set it aside for now.
- [ ] For **split builds**, repeat this process for the second set of header pins on the **HJKL-hand** half of the PCB.

*** 

## Reset switches
- [ ] Solder the reset switch to the **table-side** of the **QWERT-hand** half of the PCB.
Reset switch
- [ ] For **split builds**, also solder a reset switch to the **table-side** of the **HJKL-hand** half of the PCB.

*** 

## Switches
- [ ] Screw the standoffs securely to the **table-side** of both plates.
Attach standoffs
- [ ] If you are using Mill-max hot-swap sockets, install the sockets onto the switch legs.
- [ ] Install one of the switches into any of the key cutouts in the plate.
- [ ] Place the plate + switch assembly onto the PCB, making sure that the switch legs (or hot-swap sockets) fit through their respective holes in the PCB.
- [ ] Solder the switch legs (or hot-swap sockets if using) to the PCB.
- [ ] Repeat this process of inserting switches and soldering them in place until all the switches are installed.

*** 

## Batteries
- [ ] For **wired builds**, skip this section
- [ ] For **wireless builds**, place a battery into the battery cutout labeled **BT1** in the **QWERT-hand** half of the PCB and tape it in place.
Battery placement
- [ ] Solder the black wire to the PCB pad marked -. Then solder the red wire to the PCB pad marked +
Solder batteries
- [ ] For **split builds**, repeat the process of securing and soldering a battery into the cutout labeled **BT3** in the **HJKL-hand** half of the PCB.
- [ ] (Optional) if you want extra battery life, you can add additional batteries to battery bays **BT2** and **BT4**.

*** 

## Controller boards
- [ ] Place a controller board onto the header pins of the **QWERT-hand** half of the PCB, with the controller board components facing the PCB.
- [ ] Double check that the controller boards have all of their components facing the PCB, with the smooth side of the controller board facing the table.
- [ ] Double check that there are two through holes on the controller boards opposite the USB port that do NOT have header pins in them.
Empty through-holes
- [ ] Solder the controller boards in place.
- [ ] Trim the header pins flush with the controller boards.

*** 

## Final assembly
- [ ] (Optional) install the plastic case around the PCB, being careful to slip it around the reset switch and controller board.
- [ ] Screw the bases in place. Do not over tighten the screws, or the keyboard may bend and not sit flat.
- [ ] Apply anti-slip feet.
Foot location

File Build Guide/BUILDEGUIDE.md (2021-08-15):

# Build Guide

*** 

## Notes
* Please read all instructions before starting!
* You have a couple options as to how to build your Mercury keyboard:
  * wireless vs wired
  * split vs merged

*** 

## Check Kit Contents
- [ ] 1x QWERT-hand plate
- [ ] 1x HJKL-hand plate
- [ ] 1x QWERT-hand base
- [ ] 1x HJKL-hand base
- [ ] 1x PCB
- [ ] 2x reset switches (YD-3414)
- [ ] 24x M2 screws (4mm, wafer head)
- [ ] 12x standoffs (~3mm diameter, brass)
  - 7mm for low-profile, Kailh PG1350 Chocolate switches
  - 9mm for standard, MX style switches
- [ ] 8x Non-slip feet
- [ ] (optional) 2x batteries
- [ ] (optional) 2x 3.5mm TRRS jacks, PJ-320A
- [ ] (optional) 1x left case
- [ ] (optional) 1x right case

*** 

## Gather Additional Parts
- [ ] 42x switches, standard MX or Kailh PG1350 Chocolate
- [ ] 42x 1u keycaps
- [ ] Controller boards
  - Wireless+split: 2x Nice!Nano
  - Wireless+merged: 1x Nice!Nano
  - Wired+split: 2x ProMicro (Elite-C and Proton-C not yet verified to work)
  - Wired+merged: 1x ProMicro (Elite-C and Proton-C not yet verified to work)
- [ ] (optional for wired+split) 1x 3.5mm TRS (mono) or TRRS (stereo) cable
- [ ] (optional) 48x Mill-Max sockets
  - 7305, 0305-0 and 0305-1 only!
  - 0305-2 sockets are too long and will NOT work!

*** 

## Gather Tools
- [ ] Flush cutter
- [ ] Phillips screwdriver
- [ ] Soldering equipment
- [ ] Tweezers
- [ ] Tape

*** 

## Pre-build
- [ ] Familiarize yourself with the plates and PCB. Note the printed labels on the plates, bases, and PCB are labeled.
Labels
- [ ] This build guide uses the terms **QWERT-hand** / **HJKL-hand** and **user-side** / **table-side** to refer to the two halves of the PCB and their two respective faces. This is because the terms left/right and top/bottom get ambiguous as soon as the PCB is rotated or flipped over. Pay special attention that you are working on the correct half of the PCB and on the correct side, because it is very easy to accidentally make mistakes this way.

*** 

## TRRS sub-boards    
- [ ] For **wired+split builds**, solder both TRRS jacks to the **user-side** of both halves of the PCB.
Solder TTRS jacks
- [ ] For **all other builds** (wireless+split, wireless+merged, and wired+merged), snap off the TRRS sub-boards from the PCB.
Snap off TRRS sub-boards

*** 

## PCB halves
  - [ ] For **merged builds**, skip this section.
  - [ ] For **split builds**, cut along the divots just to the left and right of the bulge in the middle of all eight PCB bridges.
Bridge Cut Points
  - [ ] Double check that the PCB halves sit flush against each other with no gap between them.
Flush PCBs

*** 

## Controller board header pins
- [ ] Shorten two strips of header pins to 10 pins long.
Shorten header pin strips
- [ ] Insert the **short legs** of the header pin strips into the **QWERT-hand** half of the PCB, through the **table-side**.
Insert header pin strips
- [ ] Double check that the **short legs** of the header pins are inserted into the PCB.
- [ ] Double check that the header pins inserted down through the **table-side** of the PCB.
- [ ] Double check that the header pins are inserted into the **QWERT-hand** half of the PCB.
- [ ] Place the controller onto the header pins and use a piece of tape to hold everything together temporarily.
Tape controller in place
- [ ] Solder the header pins **to the PCB only**. Do not solder the controller board.
Solder header pin strips to PCB
- [ ] Remove the controller board and set it aside for now.
- [ ] For **split builds**, repeat this process for the second set of header pins on the **HJKL-hand** half of the PCB.

*** 

## Reset switches
- [ ] Solder the reset switch to the **table-side** of the **QWERT-hand** half of the PCB.
Reset switch
- [ ] For **split builds**, also solder a reset switch to the **table-side** of the **HJKL-hand** half of the PCB.

*** 

## Switches
- [ ] Screw the standoffs securely to the **table-side** of both plates.
Attach standoffs
- [ ] If you are using Mill-max hot-swap sockets, install the sockets onto the switch legs.
- [ ] Install one of the switches into any of the key cutouts in the plate.
- [ ] Place the plate + switch assembly onto the PCB, making sure that the switch legs (or hot-swap sockets) fit through their respective holes in the PCB.
- [ ] Solder the switch legs (or hot-swap sockets if using) to the PCB.
- [ ] Repeat this process of inserting switches and soldering them in place until all the switches are installed.

*** 

## Batteries
- [ ] For **wired builds**, skip this section
- [ ] For **wireless builds**, place a battery into either of the two battery cutouts in the **QWERT-hand** half of the PCB and tape it in place.
Battery placement
- [ ] Solder the black wire to the PCB pad marked -, and the red wire to the PCB pad marked +
Solder batteries
- [ ] For **split builds**, repeat the process of taping and soldering a battery to the **HJKL-hand** half of the PCB.
- [ ] (Optional) you can use up to four batteries for increased battery life. 100 mAh results in roughly one week of battery life.

*** 

## Controller boards
- [ ] Place a controller board onto the header pins of the **QWERT-hand** half of the PCB, with the controller board components facing the PCB.
- [ ] Double check that the controller boards have all of their components facing the PCB, with the smooth side of the controller board facing the table.
- [ ] Double check that there are two through holes on the controller boards opposite the USB port that do NOT have header pins in them.
Empty through-holes
- [ ] Solder the controller boards in place.
- [ ] Trim the header pins flush with the controller boards.

*** 

## Final assembly
- [ ] (Optional) install the plastic case around the PCB, being careful to slip it around the reset switch and controller board.
- [ ] Screw the bases in place. Do not over tighten the screws, or the keyboard may bend and not sit flat.
- [ ] Apply adhesive anti-slip feet.
Foot location

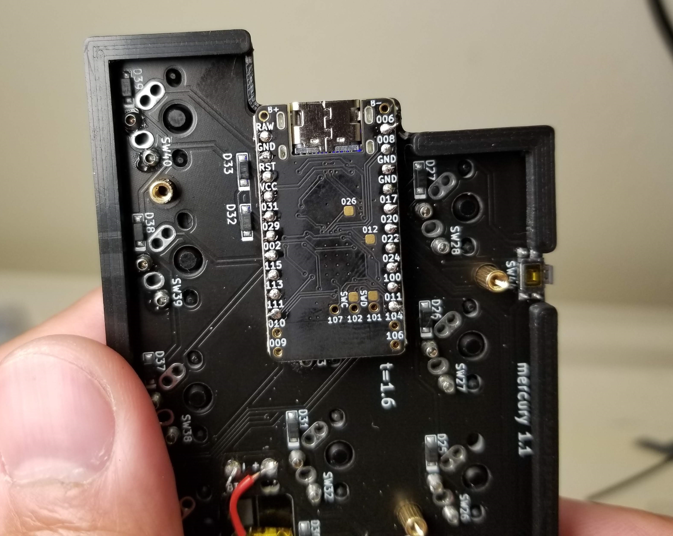
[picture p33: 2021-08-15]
images/build/smooth_side.jpg

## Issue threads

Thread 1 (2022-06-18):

Plans for release?

daniel2887, 2022-06-18:
Hi!

I've been looking for a row staggered corne-like keyboard for a while and this seems like a great fit. Any plans for releasing the PCBs and ZMK firmware source?

Thank you

jmding8, 2022-07-05:
@daniel2887 PCB files and manufacturing information have been uploaded!

daniel2887, 2022-07-05:
Awesome! Thank you for following up, and for the super detailed build guide and BOM. I really like how you minimized Z height cutting out a piece of the PCB to make room for the battery.

Couple of questions/comments:
1. It would help to split up the case file so that each half can be printed separately. (I was able to delete one of the 2 pairs in Cura, but the remaining pair is too wide for common ~235 mm^2 build plates such as Ender 3 variants)
2. What's the difference between the two case pairs? One of them is a bit thicker it seems.
3. How thick does the keyboard end up being from the bottom of the bottom plate to the top of the top plate?
4. The Firmware link from the build guide is broken (the link in [this section](https://github.com/jmding8/MercuryKeyboard/blob/main/text/build_guide.md#firmware)).
5. For folks who would like to modify the firmware/keymap, it would be helpful to include a link to [your fork](https://github.com/jmding8/zmk) of ZMK (based on the commits there I'm assuming that's what I should be compiling :-) )

jmding8, 2022-07-06:
thank you for the feedback!
1. updated
2. Yes, low-profile and full-height. I added a note about this in the manufacturing notes
3. 19mm from table to typing-surface with MBK keycaps. I added a note about this in the readme
4. fixed!
5. makes sense! I'll work on getting the shield merged into ZMK main as well, so people can compile using their GHA workflow

daniel2887, 2022-07-07:
Thank you! Closing out this issue -- thank you again for releasing the gerber files and docs! I will give the build a try and post back if I run into issues :)

jmding8, 2022-07-07:
Excited to hear that!

Closed 2022-07-07.

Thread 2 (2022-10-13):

Cpl file?

idesignstuff, 2022-10-13:
Hi! I'm excited to try building one of these. I've never had a PCB made, and went to order a set. Looks like the supplier needs a cpl pick and place file in addition to the bom.xlsx and Gerber zip file. Did you make that, and forget to add to the repo? I'm willing to learn how, but if it exists, please share! Thanks for making the files public, and it's a brilliant design!

jmding8, 2022-10-13:
I believe [Mercury.v1.2.SmdBottomLocations.xlsx](https://github.com/jmding8/MercuryKeyboard/blob/main/pcb/v1.2/Mercury.v1.2.SmdBottomLocations.xlsx) is the file you need. Let me know if I'm mistaken?

idesignstuff, 2022-10-14:
I did need that one for the bom. Also, for pick & place, another file was
required.

Christian

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

jmding8, 2022-10-16:
I'm not sure what a CPL pick and place file is. Do you have a link with the manufacturer's requirements?

idesignstuff, 2023-01-03:
Sorry, that's something I haven't learned yet.

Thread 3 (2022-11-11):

Have you ever considered a 60/65 version?

johncalvinyoung, 2022-11-11:
I really like the look of Mercury, and (coming from a UHK) it looks closer to what I'd like to use than the vast vast majority of fully wireless or low-profile keyboards. There really seem to not be many people sticking to traditional row-staggered layouts in that space.

That said, I'm not really interested in switching to a 40% layout personally.

Have you ever considered / how much effort would it be to design out a 60% layout on similar principles? I've been thinking about forking and attempting that redesign myself, but I'm pretty new to the PCB space so I'm not sure where to start.

jmding8, 2022-11-11:
Yeah! Indeed I have, even thought about doing a breakaway version, but decided against because I couldn't find a way to add the numbers row in a way that worked for me aesthetically. You should totally give pcb design a shot, I was also completely new to it and this guide was really helpful https://wiki.ai03.com/books/pcb-design/page/pcb-guide-part-1---preparations

johncalvinyoung, 2022-11-14:
@jmding8 Cool! As I said I'm very content with the UHK layout so would probably be thinking something similar, though number rows in general are a bit of a pain on trad-layout split keyboards.

Might download KiCAD and give it a try over the holidays.

johncalvinyoung, 2022-11-14:
One more question when you get a chance--I notice there's not an edge-on photo of your keyboard anywhere I can find. Mind posting a photo of your 19mm build?

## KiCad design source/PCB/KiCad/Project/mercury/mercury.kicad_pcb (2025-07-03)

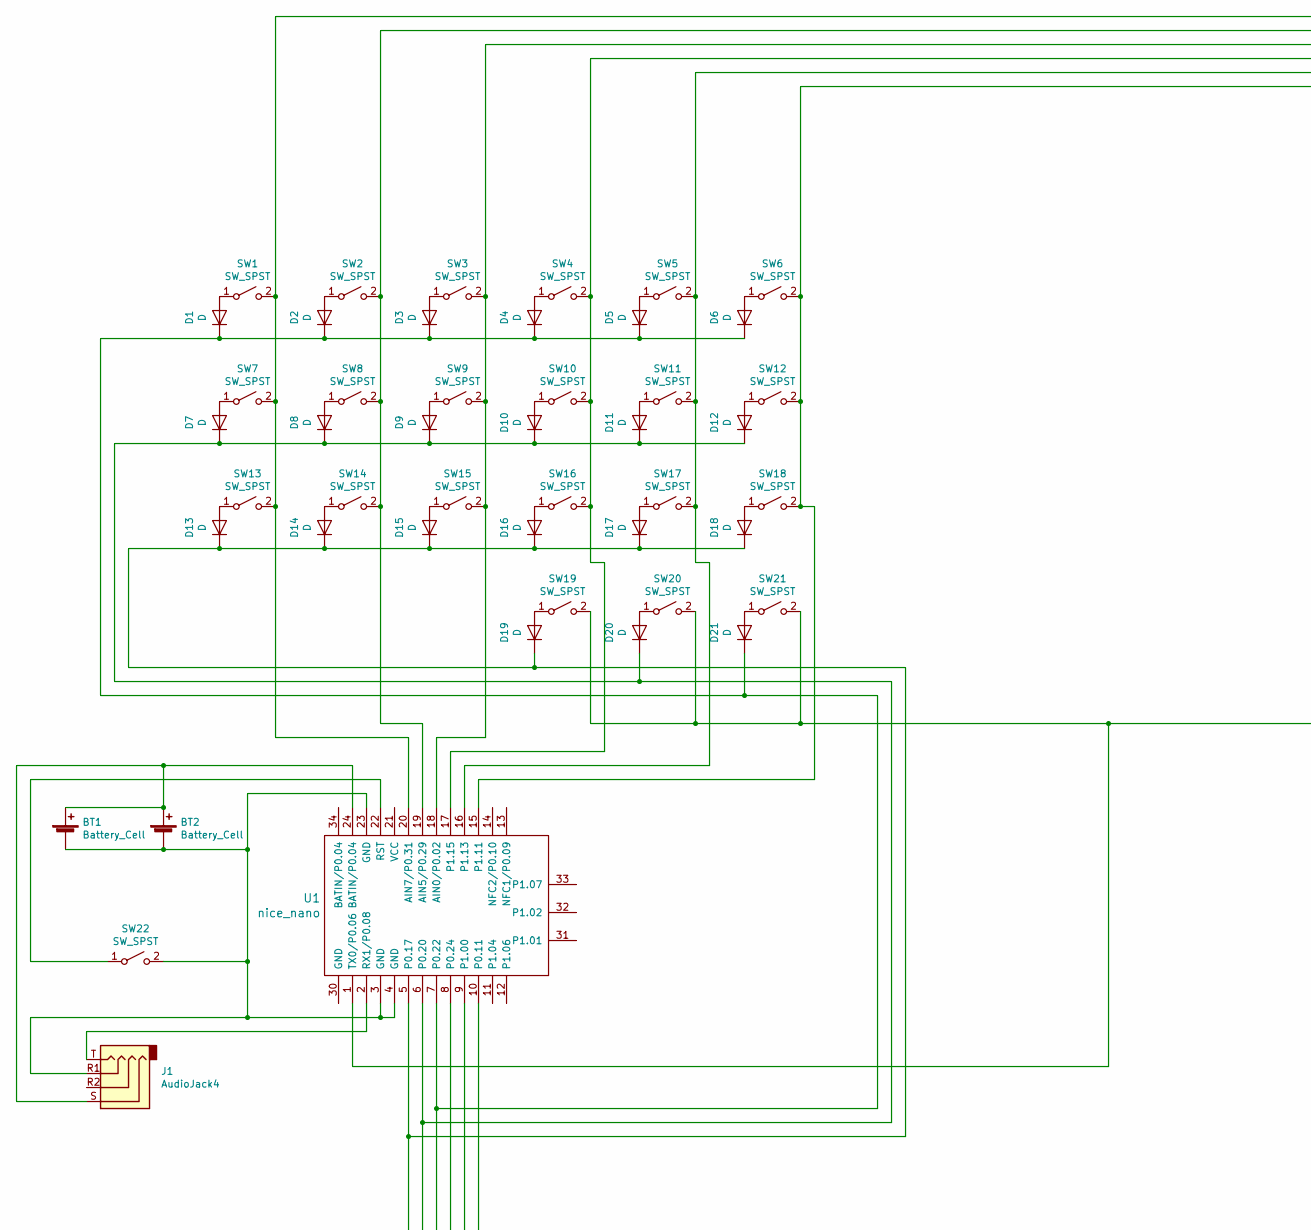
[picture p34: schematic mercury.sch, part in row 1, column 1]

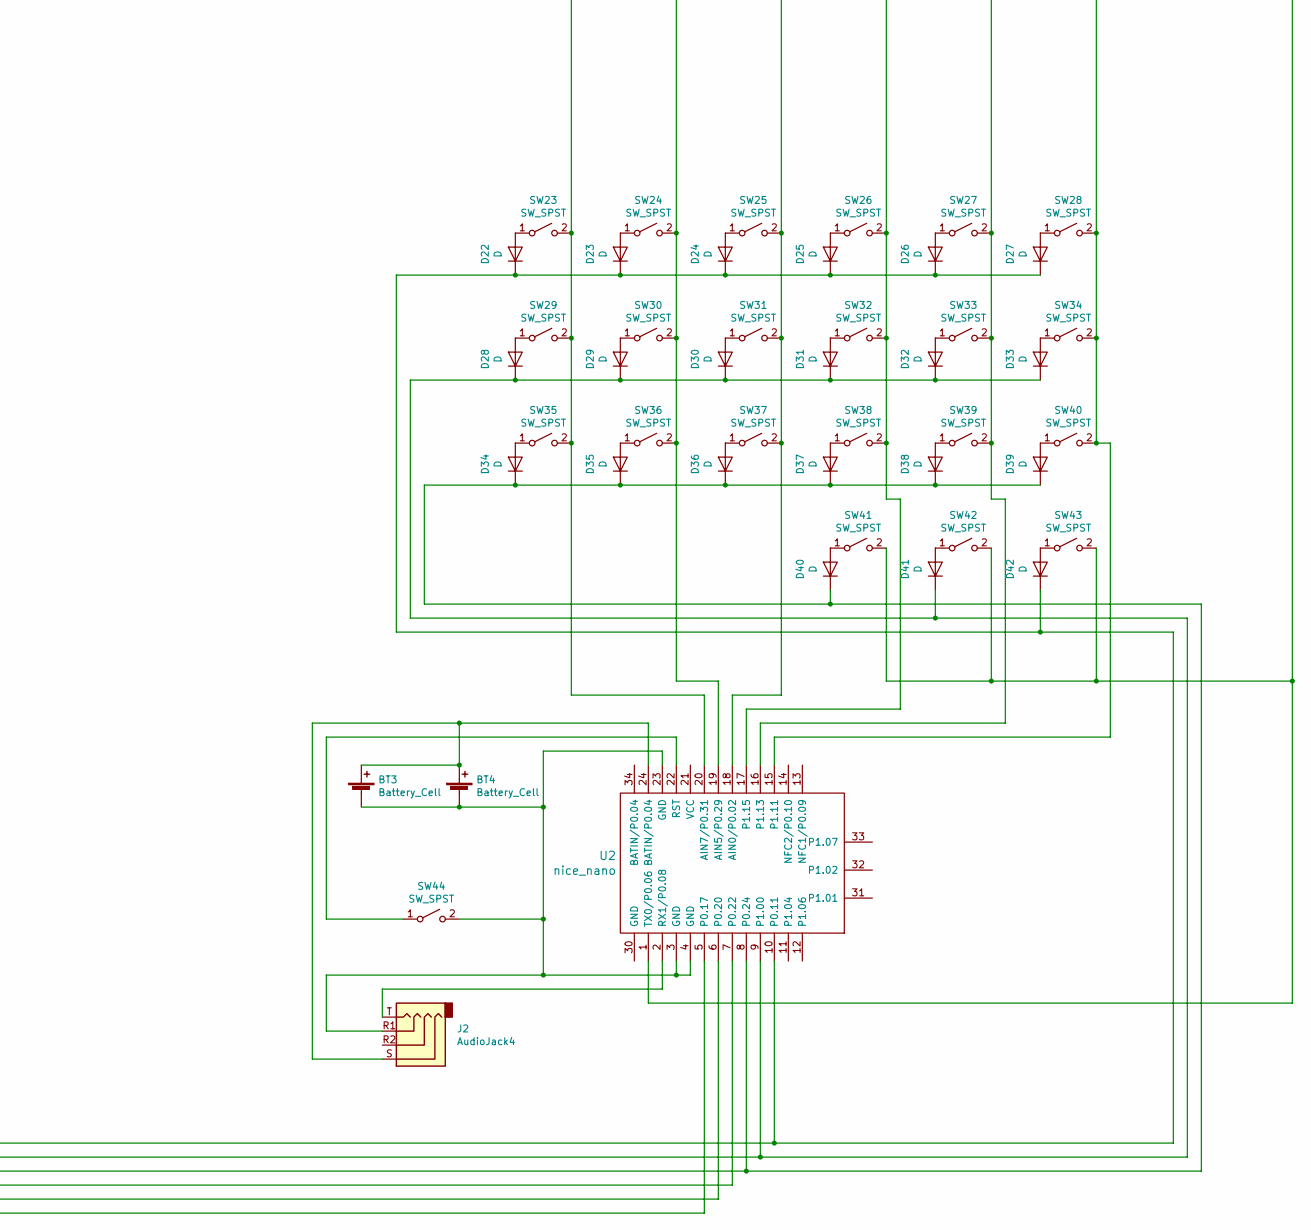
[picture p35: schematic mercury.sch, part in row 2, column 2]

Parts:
BT1, BT2, BT3, BT4: Battery_Cell; Battery-TH
D1, D2, D3, D4, D5, D6, D7, D8, D9, D10, D11, D12, D13, D14, D15, D16, D17, D18, D19, D20, D21, D22, D23, D24, D25, D26, D27, D28, D29, D30, D31, D32, D33, D34, D35, D36, D37, D38, D39, D40, D41, D42: D; D_SOD123
J1, J2: AudioJack4; TRRS-PJ-320A
SW1, SW2, SW3, SW4, SW5, SW6, SW7, SW8, SW9, SW10, SW11, SW12, SW13, SW14, SW15, SW16, SW17, SW18, SW19, SW20, SW21, SW23, SW24, SW25, SW26, SW27, SW28, SW29, SW30, SW31, SW32, SW33, SW34, SW35, SW36, SW37, SW38, SW39, SW40, SW41, SW42, SW43: SW_SPST; MxAlpsChoc-Classic
SW22, SW44: SW_SPST; YD-3414
U1, U2: nice_nano; nice_nano_over_mount

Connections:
unnamed: BT1.1 (+), BT2.1 (+), J1.S, U1.24 (BATIN/P0.04)
unnamed: BT1.2 (-), BT2.2 (-), J1.R1, SW22.2 (B), U1.3 (GND), U1.4 (GND), U1.23 (GND)
unnamed: BT3.1 (+), BT4.1 (+), J2.S, U2.24 (BATIN/P0.04)
unnamed: BT3.2 (-), BT4.2 (-), J2.R1, SW44.2 (B), U2.3 (GND), U2.4 (GND), U2.23 (GND)
unnamed: D1.1 (K), D2.1 (K), D3.1 (K), D4.1 (K), D5.1 (K), D6.1 (K), D21.1 (K), U1.7 (P0.22), U2.7 (P0.22)
unnamed: D1.2 (A), SW1.1 (A)
unnamed: D2.2 (A), SW2.1 (A)
unnamed: D3.2 (A), SW3.1 (A)
unnamed: D4.2 (A), SW4.1 (A)
unnamed: D5.2 (A), SW5.1 (A)
unnamed: D6.2 (A), SW6.1 (A)
unnamed: D7.2 (A), SW7.1 (A)
unnamed: D8.2 (A), SW8.1 (A)
unnamed: D9.2 (A), SW9.1 (A)
unnamed: D7.1 (K), D8.1 (K), D9.1 (K), D10.1 (K), D11.1 (K), D12.1 (K), D20.1 (K), U1.6 (P0.20), U2.6 (P0.20)
unnamed: D10.2 (A), SW10.1 (A)
unnamed: D11.2 (A), SW11.1 (A)
unnamed: D12.2 (A), SW12.1 (A)
unnamed: D13.1 (K), D14.1 (K), D15.1 (K), D16.1 (K), D17.1 (K), D18.1 (K), D19.1 (K), U1.5 (P0.17), U2.5 (P0.17)
unnamed: D13.2 (A), SW13.1 (A)
unnamed: D14.2 (A), SW14.1 (A)
unnamed: D15.2 (A), SW15.1 (A)
unnamed: D16.2 (A), SW16.1 (A)
unnamed: D17.2 (A), SW17.1 (A)
unnamed: D18.2 (A), SW18.1 (A)
unnamed: D19.2 (A), SW19.1 (A)
unnamed: D20.2 (A), SW20.1 (A)
unnamed: D21.2 (A), SW21.1 (A)
unnamed: D22.1 (K), D23.1 (K), D24.1 (K), D25.1 (K), D26.1 (K), D27.1 (K), D42.1 (K), U1.10 (P0.11), U2.10 (P0.11)
unnamed: D22.2 (A), SW23.1 (A)
unnamed: D23.2 (A), SW24.1 (A)
unnamed: D24.2 (A), SW25.1 (A)
unnamed: D25.2 (A), SW26.1 (A)
unnamed: D26.2 (A), SW27.1 (A)
unnamed: D27.2 (A), SW28.1 (A)
unnamed: D28.1 (K), D29.1 (K), D30.1 (K), D31.1 (K), D32.1 (K), D33.1 (K), D41.1 (K), U1.9 (P1.00), U2.9 (P1.00)
unnamed: D28.2 (A), SW29.1 (A)
unnamed: D29.2 (A), SW30.1 (A)
unnamed: D30.2 (A), SW31.1 (A)
unnamed: D31.2 (A), SW32.1 (A)
unnamed: D32.2 (A), SW33.1 (A)
unnamed: D33.2 (A), SW34.1 (A)
unnamed: D34.1 (K), D35.1 (K), D36.1 (K), D37.1 (K), D38.1 (K), D39.1 (K), D40.1 (K), U1.8 (P0.24), U2.8 (P0.24)
unnamed: D34.2 (A), SW35.1 (A)
unnamed: D35.2 (A), SW36.1 (A)
unnamed: D36.2 (A), SW37.1 (A)
unnamed: D37.2 (A), SW38.1 (A)
unnamed: D38.2 (A), SW39.1 (A)
unnamed: D39.2 (A), SW40.1 (A)
unnamed: D40.2 (A), SW41.1 (A)
unnamed: D41.2 (A), SW42.1 (A)
unnamed: D42.2 (A), SW43.1 (A)
unnamed: J1.T, U1.2 (RX1/P0.08)
unnamed: J2.T, U2.2 (RX1/P0.08)
unnamed: SW1.2 (B), SW7.2 (B), SW13.2 (B), SW23.2 (B), SW29.2 (B), SW35.2 (B), U1.20 (AIN7/P0.31), U2.20 (AIN7/P0.31)
unnamed: SW4.2 (B), SW10.2 (B), SW16.2 (B), SW26.2 (B), SW32.2 (B), SW38.2 (B), U1.17 (P1.15), U2.17 (P1.15)
unnamed: SW5.2 (B), SW11.2 (B), SW17.2 (B), SW27.2 (B), SW33.2 (B), SW39.2 (B), U1.16 (P1.13), U2.16 (P1.13)
unnamed: SW6.2 (B), SW12.2 (B), SW18.2 (B), SW28.2 (B), SW34.2 (B), SW40.2 (B), U1.15 (P1.11), U2.15 (P1.11)
unnamed: SW2.2 (B), SW8.2 (B), SW14.2 (B), SW24.2 (B), SW30.2 (B), SW36.2 (B), U1.19 (AIN5/P0.29), U2.19 (AIN5/P0.29)
unnamed: SW3.2 (B), SW9.2 (B), SW15.2 (B), SW25.2 (B), SW31.2 (B), SW37.2 (B), U1.18 (AIN0/P0.02), U2.18 (AIN0/P0.02)
unnamed: SW19.2 (B), SW20.2 (B), SW21.2 (B), SW41.2 (B), SW42.2 (B), SW43.2 (B), U1.1 (TX0/P0.06), U2.1 (TX0/P0.06)
unnamed: SW22.1 (A), U1.22 (RST)
unnamed: SW44.1 (A), U2.22 (RST)

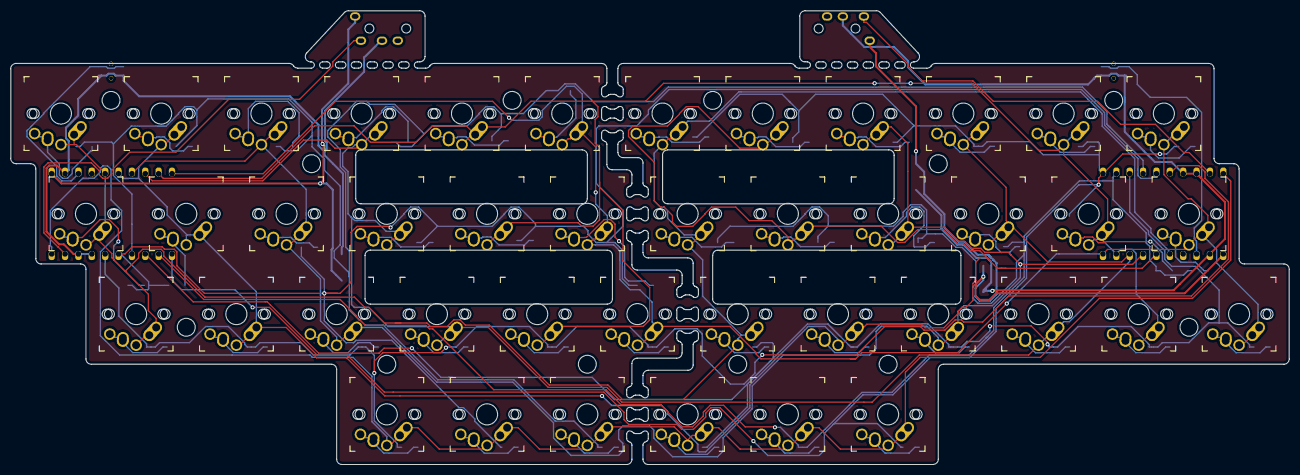
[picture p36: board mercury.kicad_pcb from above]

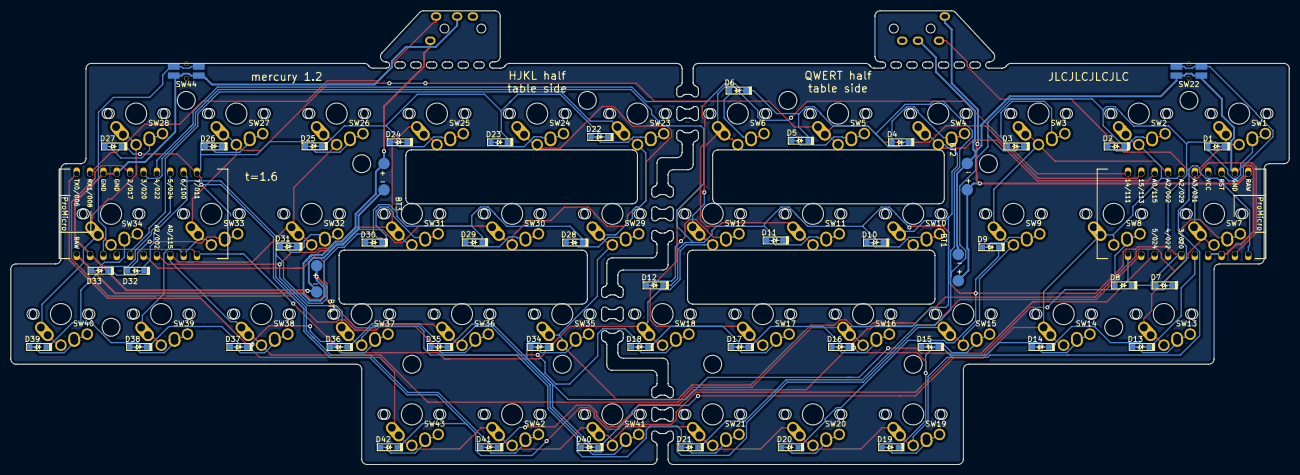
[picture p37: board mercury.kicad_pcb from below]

Board: 2 copper layers, 242.9 x 86.2 mm, 94 parts (48 on the bottom side), 63 nets.

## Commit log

2021-08-15 fix typo number of mill max sockets
2021-09-22 add case files
    [LowProfile7mm.stl, Standard9mm.stl]
2021-09-22 unify case files, update instructions and include presliced project
    [LowProfile7mm.stl, PrusaSlicerPresliced.3mf, Standard9mm.stl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]
2021-09-24 revamp sliced case files and add print images
    [PrusaSlicerPresliced.3mf, SplitPresliced.3mf, UnifiedCase.stl]
2021-09-24 add links to resources
    [SplitCaseWithPrusaSlicerSettings.3mf]
2022-01-15 build guide: trim header pins, remove and reinstall header plastic spacer, trim switch legs, insert switches into plate before soldering
2022-01-15 build guide: clarify standoff specifications
2022-01-15 separate bill of materials, and standardize snake case
    [split_case_with_prusa_slicer_settings.3mf]
2022-01-15 link to print instructions from BOM
2022-07-04 add pcb files
    [Mercury.v1.2.SmdBom.xlsx, Mercury.v1.2.SmdBottomLocations.xlsx]
2022-07-05 reword intro paragraph, include reference to wings
2022-07-06 split case files
    [split_case_with_prusa_slicer_settings.3mf]
